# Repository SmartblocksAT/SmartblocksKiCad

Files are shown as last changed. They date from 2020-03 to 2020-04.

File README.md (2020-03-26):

# SmartblocksKiCad
These are the schematics-, assembly-, layout plans and other stuff for KiCad.

Smartblocks is a project by students at the [HTL-Waidhofen](https://htlwy.at/).

Smartblocks logo

# Goal
The Goal is to develop a microcontroller environment for students, which should make it easy for them to start programming with microcontrollers.

We started this Project in February of 2019.
In this time a rough concept that defined the function and dimensions was created and presented to teachers who would later use this project. A proof of concept has been worked on in the summer in order to get an idea of how the project could develop and look like.

As soon as the project was successfully submitted, the existing elements of the prototype, such as the web interface, sample programs and the practical structure, were revised and improved.

# Components
This Project consists of two Components:

 - The webinterface (can be found [here](https://github.com/SmartblocksAT/SmartblocksWeb))
 - ESP32 Library (can be found [here](https://github.com/SmartblocksAT/SmartblocksLibrary))
 - Schematics, etc. (this repository)

## Who is responsible for this?
Lukas Kamleitner <lukas.kamleitner@smartblocks.dev>

Maximilian Mernacher <maximilian.mernacher@smartblocks.dev>

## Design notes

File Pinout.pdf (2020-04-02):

Links J6/J7 | | | Vorne J2/J3
Gerät | Pin | I/O | Gerät | Pin | I/O
Analog IN24 | 33 | I | LCD | 21,22 | BUS
Analog IN24 | 34 | I | Taster | 2 | I
Potentiometer | 35 | I | Taster | 13 | I
Analog IN10 | 36 | I | Taster | 32 | I
Analog IN10 | 39 | I | Led | 4 | O
DAC | 25 | O | Led | 16 | O
DAC | 26 | O | Led | 17 | O
Vorne J2/J3 | | | Rechts J4/J5
Gerät | Pin | I/O | Gerät | Pin | I/O
Realis | 13 | O | Ultraschall(HC-SR04) | 14,27 | I/O
Realis | 4 | O | Temperatur(Si7020-A20) | 21,22 | BUS
Taster | 2 | I | Acelerometer (LIS3DHTR) | 21,22 | BUS
Taster | 32 | I | Lichtsensor(OPT3001) | 21,22 | BUS
DO 24V | 16 | O
DO 24V | 17 | O
Modul 1 | Modul 2
Modul 3 | Modul 4

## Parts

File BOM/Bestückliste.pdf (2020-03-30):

Referenz | Wert | Footprint | Anzahl Sonsitges
C1 C2 C6 C7 C8 C9 C10 C13 C14 C15 C16 C17 C18 C19 C20 C21 C22 C23 C24 C25 C26 C27 C28 C29 C30 | 47pF | C_0805_2012Metric | 25 Capacitor 0805 47pF
C3 C5 | 100pF | C_0805_2012Metric | 2 Capacitor 0805 100pF
C4 C11 C32 C33 | 1uF | C_0805_2012Metric | 4 Capacitor 0805 1uF
D1 | SP0503BAHT | SOT-143 | 1 SP0503BAHT SOT-143
D2 | 1N5819HW-7-F | SOD 123 | 1 1N5819HW-7-F SOD-123
D3 | Led Smd 1206 | LED_1206_3216Metric | 1 Led Smd 1206
J1 | Micro-B_Wuerth_629105150521 | USB_Micro-B_Wuerth_629105150521_CircularHoles | 1 USB B Micro-B_Wuerth_629105150521
J2 J4 J6 | Stecker Messerleiste WSL 10G | SHDR10W64P254X254_2X5_2032X880X915P | 3 Stecker Messerleiste WSL 10G
J3 | Stecker Messerleiste WSL 10G | SHDR10W64P254X254_2X5_2032X880X915P | 1 Stecker Messerleiste WSL 10G
J5 | Stecker Messerleiste WSL 10G | SHDR10W64P254X254_2X5_2032X880X915P | 1 Stecker Messerleiste WSL 10G
J7 | Stecker Messerleiste WSL 10G | SHDR10W64P254X254_2X5_2032X880X915P | 1 Stecker Messerleiste WSL 10G
Q1 Q2 | BC817 | SOT-23 | 2 BC817 SOT-23
R1 R2 | 22R | R_0805_2012Metric | 2 Resistor 0805 22R
R13 | 2k2 | R_0805_2012Metric | 1 Resistor 0805 2k2
R14 | 22,1k | R_0805_2012Metric | 1 Resistor 0805 22,1k
R15 | 47,5k | R_0805_2012Metric | 1 Resistor 0805 47,5k
R3 R4 R8 R33 R34 | 10k | R_0805_2012Metric | 5 Resistor 0805 10k
R35 | 1M | R_0805_2012Metric | 1 Resistor 0805 1M
R36 | 330R | R_0805_2012Metric | 1 Resistor 0805 330R
R5 R6 R7 R10 R12 R16 R17 R18 R19 R20 R21 R22 R23 R24 R25 R26 R27 R28 R29 R30 R31 R32 | 47R | R_0805_2012Metric | 22 Resistor 0805 47R
R9 R11 | 4k7 | R_0805_2012Metric | 2 Resistor 0805 4k7
S1 | B3SL-1002P | SW_SPST_B3SL-1002P | 1 Button SMD B3SL-1002P
S2 | B3SL-1002P | SW_SPST_B3SL-1002P | 1 Button SMD B3SL-1002P
U1 | CP2102N-A01-GQFN24 | QFN-24-1EP_4x4mm_P0.5mm_EP2.6x2.6mm | 1 CP2102N-A01-G QFN24
U2 | EP32-WROOM-32D | ESP32-WROOM-32U | 1 EP32-WROOM-32D
U3 | AMS1117-3.3 | SOT-223-3_TabPin2 | 1 AMS1117-3.3 SOT-223-3

## Mainboard

Referenz | Wert | Footprint | Anzahl Sonstiges
C1 C2 C3 C4 C5 C6 C7 C8 C9 10nF | C_0805_2012Metric | 9 Capacitor 0805 10nF
J3 | Stecker Messerleiste WSL 10G | SHDR10W64P254X254_2X5_2032X880X915P | 1 Stecker Messerleiste WSL 10G
J1 | Stecker Messerleiste WSL 10G | SHDR10W64P254X254_2X5_2032X880X915P | 1 Stecker Messerleiste WSL 10G
J2 J4 J5 J6 | TBL 127B p2 | TBL_127B 2 | 4 TBL 127B p2
R5 | 100R | R_0805_2012Metric | 1 Resistor 0805 100R
R_POT1 | 10K_Pot | Potentiometer_Bourns_PRS11S_Vertical | 1 10K_Pot Bourns_PRS11S_Vertical
R1 R3 R6 R8 | 10k | R_0805_2012Metric | 4 Resistor 0805 10k
R2 R9 | 1k6 | R_0805_2012Metric | 2 Resistor 0805 1k6
R4 R7 | 4k7 | R_0805_2012Metric | 2 Resistor 0805 4k7
U1 U2 | AD8603 | TSOT-23-5 | 2 AD8603 TSOT-23-5

# Modul1

Referenz | Wert | Footprint | Anazhl Sonstiges
C1 C2 C3 C4 C5 10nF | C_0805_2012Metric | 5 Capacitor 0805 10nF
D1 D2 D3 | Led THT d5mm | D_DO-15_P5.08mm_Vertical_KathodeUp | 3 Led d5mm
J1 | Stecker Messerleiste WSL 10G | SHDR10W64P254X254_2X5_2032X880X915P | 1 Stecker Messerleiste WSL 10G
J2 | Stecker Messerleiste WSL 10G | SHDR10W64P254X254_2X5_2032X880X915P | 1 Stecker Messerleiste WSL 10G
J3 | LCD Dobrovitz | LCD_dobrovitz | 1 LCD Dobrovitz
Q1 | BC817 | SOT-23 | 1 BC817 SOT-23
R1 R2 R6 R8 | 10k | R_0805_2012Metric | 4 Resistor 0805 10k
R3 R5 R7 | 220R | R_0805_2012Metric | 3 Resistor 0805 220R
RV1 | R_POT 10k | Potentiometer_Bourns_3314G_Vertical | 1 R_POT 10k Bourns_3314G_Vertical
SW1 SW3 SW4 B077FH7TGD Taster | Druckschalter | 3 B077FH7TGD Taster
U1 | PCF8574 | SOIC-16W_7.5x10.3mm_P1.27mm | 1 PCF8574AT SOIC-16W

# Modul 2

Referenz | Wert | Footprint | Anzahl Sonstiges
C3 C4 C9 C10 | 100nF | C_0805_2012Metric | 4 Capacitor 0805 100nF
C1 C2 | 10nF | C_0805_2012Metric | 2 Capacitor 0805 10nF
C13 C14 | 10uF | CP_Radial_D5.0mm_P2.00mm | 2 Capacitor 0805 10uF
C5 C6 C7 C8 C11 C12 1uF | C_0805_2012Metric | 6 Capacitor 0805 1uF
D1 D2 D3 D4 | 1N4148 | D_SOD-123 | 4 1N4148
J2 | Stecker Messerleiste WSL 10G SHDR10W64P254X254_2X5_2032X880X915P | 1 Stecker Messerleiste WSL 10G
J3 | Stecker Messerleiste WSL 10G SHDR10W64P254X254_2X5_2032X880X915P | 1 Stecker Messerleiste WSL 10G
J1 J5 | TBL 127B p2 | TBL_127B 2 | 2 TBL 127B p2
J4 J6 | TBL 127B p3 | TBL_127B 3 | 2 TBL 127B p3
K1 K2 | Songle Relay TypC | Relay_SPDT_SANYOU_SRD_Series_Form_C | 2 Songle Relay TypC
Q9 Q10 | BC817 | SOT-23 | 2 BC817 SOT-23
Q1 Q2 Q3 Q4 | NVD5C454NT4G | TO-252-2 | 4 NVD5C454NT4G TO-252-2
R1 R2 | 100K | R_0805_2012Metric | 2 Resistor 0805 100k
R3 R4 | 100R | R_0805_2012Metric | 2 Resistor 0805 100R
R10 R11 R12 R14 | 10K | R_0805_2012Metric | 4 Resistor 0805 10k
R9 R13 | 5K6 | R_0805_2012Metric | 2 Resistor 0805 5k6
SW1 SW2 | SW_DIP_x01 | Druckschalter | 2 B077FH7TGD Taster
U1 U2 | si8234bb | SOIC-16W_7.5x10.3mm_P1.27mm | 2 si8234bb SOIC-16W

# Modul3

Referenz | Wert | Footprint | Anzahl | Sonsitges
AC1 | LIS3DHTR | XDCR_LIS3DHTR | | 1 LIS3DHTR LGA-16
C1 C4 C5 C6 | 1pF | C_0805_2012Metric | | 4 Capacitor 0805 1pF
C2 C3 | 47pF | C_0805_2012Metric | | 2 Capacitor 0805 1pF
IC1 | OPT3001DNPR | OPT3001DNPR | | 1 OPT3001DNPR USON-6
J5 | Stecker Messerleiste WSL 10G | SHDR10W64P254X254_2X5_2032X880X915P | | 1 Stecker Messerleiste WSL 10G
J4 | Stecker Messerleiste WSL 10G | SHDR10W64P254X254_2X5_2032X880X915P | | 1 Stecker Messerleiste WSL 10G
J1 | HC-SR04 | XCVR_HC-SR04 | | 1 HC-SR04
R3 R4 | 10K | R_0805_2012Metric | | 2 Resistor 0805 10k
R1 R2 | 47R | R_0805_2012Metric | | 2 Resistor 0805 47R
U1 | Si7020-A20 DFN-6 | DFN-6-1EP_3x3mm_P1mm_EP1.5x2.4mm | | 1 Si7020-A20 DFN_QFN

# Modul4

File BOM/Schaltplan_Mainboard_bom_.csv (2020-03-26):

Component | Description | Part | References | Value | Footprint | Quantity Per PCB | Datasheet
1 | Unpolarized capacitor | C | C3 C5 | 100pF | C_0805_2012Metric | 2 | Capacitor 0805 100pF
2 | Unpolarized capacitor | C | C4 C11 C32 C33 | 1uF | C_0805_2012Metric | 4 | Capacitor 0805 1uF
3 | Unpolarized capacitor | C | C1 C2 C6 C7 C8 C9 C10 C13 C14 C15 C16 C17 C18 C19 C20 C21 C22 C23 C24 C25 C26 C27 C28 C29 C30 | 47pF | C_0805_2012Metric | 25 | Capacitor 0805 47pF
4 | 30V 1A Schottky Barrier Rectifier Diode, DO-41 | 1N5818 | D2 | 1N5819HW-7-F | D_ | 1 | 1N5819HW-7-F SOD-123
5 | LED generic | LED | D3 | Led Spannung | LED_1206_3216Metric | 1 | Led Smd 1206
6 |  | SP0503BAHT-Power_Protection | D1 | SP0503BAHT | SOT-143 | 1 | SP0503BAHT SOT-143
7 | Generic connector, double row, 02x01, this symbol is compatible with counter-clockwise, top-bottom and odd-even numbering schemes., script generated (kicad-library-utils/schlib/autogen/connector/) | Conn_02x01 | J5 | Conn_Rechts | SHDR10W64P254X254_2X5_2032X880X915P | 1 | Stecker Messerleiste WSL 10G
8 | Generic connector, double row, 02x05, odd/even pin numbering scheme (row 1 odd numbers, row 2 even numbers), script generated (kicad-library-utils/schlib/autogen/connector/) | Conn_02x05_Odd_Even | J2 J4 J6 | ConnectorBUS_Front | SHDR10W64P254X254_2X5_2032X880X915P | 3 | Stecker Messerleiste WSL 10G
9 | Generic connector, double row, 02x03, odd/even pin numbering scheme (row 1 odd numbers, row 2 even numbers), script generated (kicad-library-utils/schlib/autogen/connector/) | Conn_02x03_Odd_Even | J3 | Connector_Front | SHDR10W64P254X254_2X5_2032X880X915P | 1 | Stecker Messerleiste WSL 10G
10 | Generic connector, double row, 02x04, odd/even pin numbering scheme (row 1 odd numbers, row 2 even numbers), script generated (kicad-library-utils/schlib/autogen/connector/) | Conn_02x04_Odd_Even | J7 | Connector_Links | SHDR10W64P254X254_2X5_2032X880X915P | 1 | Stecker Messerleiste WSL 10G
11 | USB Micro Type B connector | USB_B_Micro | J1 | Micro-B_Wuerth_629105150521 | USB_Micro-B_Wuerth_629105150521_CircularHoles | 1 | USB B Micro-B_Wuerth_629105150521
12 | 0.8A Ic, 45V Vce, NPN Transistor, SOT-23 | BC817 | Q1 Q2 | BC817 | SOT-23 | 2 | BC817 SOT-23
13 | Resistor | R | R3 R4 R8 R33 R34 | 10k | R_0805_2012Metric | 5 | Resistor 0805 10k
14 | Resistor | R | R35 | 1M NC | R_0805_2012Metric | 1 | Resistor 0805 1M
15 | Resistor | R | R14 | 22,1k | R_0805_2012Metric | 1 | Resistor 0805 22,1k
16 | Resistor | R | R1 R2 | 22R | R_0805_2012Metric | 2 | Resistor 0805 22R
17 | Resistor | R | R13 | 2k2 | R_0805_2012Metric | 1 | Resistor 0805 2k2
18 | Resistor | R | R36 | 330R | R_0805_2012Metric | 1 | Resistor 0805 330R
19 | Resistor | R | R15 | 47,5k | R_0805_2012Metric | 1 | Resistor 0805 47,5k
20 | Resistor | R | R5 R6 R7 R10 R12 R16 R17 R18 R19 R20 R21 R22 R23 R24 R25 R26 R27 R28 R29 R30 R31 R32 | 47R | R_0805_2012Metric | 22 | Resistor 0805 47R
21 | Resistor | R | R9 R11 | 4k7 | R_0805_2012Metric | 2 | Resistor 0805 4k7
22 | 1x DIP Switch, Single Pole Single Throw (SPST) switch, small symbol | SW_DIP_x01 | S1 | BOOT Option | SW_SPST_B3SL-1002P | 1 | Button SMD B3SL-1002P
23 | 1x DIP Switch, Single Pole Single Throw (SPST) switch, small symbol | SW_DIP_x01 | S2 | Reset | SW_SPST_B3SL-1002P | 1 | Button SMD B3SL-1002P
24 | 1A Low Dropout regulator, positive, 3.3V fixed output, SOT-223 | AMS1117-3.3 | U3 | AMS1117-3.3 | SOT-223-3_TabPin2 | 1 | AMS1117-3.3 SOT-223-3
25 | USB to UART master bridge | CP2102N-A01-GQFN24 | U1 | CP2102N-A01-GQFN24 | QFN-24-1EP_4x4mm_P0.5mm_EP2.6x2.6mm | 1 | CP2102N-A01-G QFN24
26 |  | EP32-WROOM-32D | U2 | EP32-WROOM-32D | ESP32-WROOM-32U | 1 | EP32-WROOM-32D
Component Groups: | 26
Component Count: | 84
Fitted Components: | 84
Number of PCBs: | 1
Total components: | 84
Schematic Version:
Schematic Date:
PCB Variant: | [u'default']
BoM Date: | 15.03.2020 14:47:03
Schematic Source: | Schaltplan_Mainboard.sch
KiCad Version: | Eeschema (5.0.0)

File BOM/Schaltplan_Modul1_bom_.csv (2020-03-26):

Component | Description | Part | References | Value | Footprint | Quantity Per PCB | Datasheet
1 | Unpolarized capacitor | C | C1 C2 C3 C4 C5 C6 C7 C8 C9 | 10nF | C_0805_2012Metric | 9 | Capacitor 0805 10nF
2 | Generic connector, double row, 02x05, odd/even pin numbering scheme (row 1 odd numbers, row 2 even numbers), script generated (kicad-library-utils/schlib/autogen/connector/) | Conn_02x05_Odd_Even | J3 | ConnectorBUS_Links | SHDR10W64P254X254_2X5_2032X880X915P | 1 | Stecker Messerleiste WSL 10G
3 | Generic connector, double row, 02x04, odd/even pin numbering scheme (row 1 odd numbers, row 2 even numbers), script generated (kicad-library-utils/schlib/autogen/connector/) | Conn_02x04_Odd_Even | J1 | Connector_Links | SHDR10W64P254X254_2X5_2032X880X915P | 1 | Stecker Messerleiste WSL 10G
4 | Generic screw terminal, single row, 01x02, script generated (kicad-library-utils/schlib/autogen/connector/) | Screw_Terminal_01x02 | J2 J4 J5 J6 | X_DAC | TBL_127B 2 | 4 | TBL 127B p2
5 | Resistor | R | R5 | 100R | R_0805_2012Metric | 1 | Resistor 0805 100R
6 | Potentiometer | R_POT | R_POT1 | 10K_Pot | Potentiometer_Bourns_PRS11S_Vertical | 1 | 10K_Pot Bourns_PRS11S_Vertical
7 | Resistor | R | R1 R3 R6 R8 | 10k | R_0805_2012Metric | 4 | Resistor 0805 10k
8 | Resistor | R | R2 R9 | 1k6 | R_0805_2012Metric | 2 | Resistor 0805 1k6
9 | Resistor | R | R4 R7 | 4k7 | R_0805_2012Metric | 2 | Resistor 0805 4k7
10 | Precision Micropower, Low Noise CMOS, Rail-to-Rail Input/Output Operational Amplifier, TSOT-23-5 | AD8603 | U1 U2 | AD8603 | TSOT-23-5 | 2 | AD8603 TSOT-23-5
Component Groups: | 10
Component Count: | 27
Fitted Components: | 27
Number of PCBs: | 1
Total components: | 27
Schematic Version:
Schematic Date:
PCB Variant: | [u'default']
BoM Date: | 15.03.2020 14:37:26
Schematic Source: | Schaltplan_Modul1.sch
KiCad Version: | Eeschema (5.0.0)

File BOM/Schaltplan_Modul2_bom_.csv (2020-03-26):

Component | Description | Part | References | Value | Footprint | Quantity Per PCB | Datasheet
1 | Unpolarized capacitor | C | C1 C2 C3 C4 C5 | 10nF | C_0805_2012Metric | 5 | Capacitor 0805 10nF
2 | LED generic | LED | D1 D2 D3 | Led THT | D_DO-15_P5.08mm_Vertical_KathodeUp | 3 | Led Smd 1206 d5mm
3 | Generic connector, double row, 02x05, odd/even pin numbering scheme (row 1 odd numbers, row 2 even numbers), script generated (kicad-library-utils/schlib/autogen/connector/) | Conn_02x05_Odd_Even | J1 | ConnectorBUS_Front | SHDR10W64P254X254_2X5_2032X880X915P | 1 | Stecker Messerleiste WSL 10G
4 | Generic connector, double row, 02x03, odd/even pin numbering scheme (row 1 odd numbers, row 2 even numbers), script generated (kicad-library-utils/schlib/autogen/connector/) | Conn_02x03_Odd_Even | J2 | Connector_Front | SHDR10W64P254X254_2X5_2032X880X915P | 1 | Stecker Messerleiste WSL 10G
5 | Generic connector, single row, 01x16, script generated (kicad-library-utils/schlib/autogen/connector/) | Conn_01x16_Male | J3 | LCD Dobrovitz | LCD_dobro | 1 | LCD Dobrovitz
6 | 0.8A Ic, 45V Vce, NPN Transistor, SOT-23 | BC817 | Q1 | BC817 | SOT-23 | 1 | BC817 SOT-23
7 | Resistor | R | R1 R2 R6 R8 | 10k | R_0805_2012Metric | 4 | Resistor 0805 10k
8 | Resistor | R | R3 R5 R7 | 220R | R_0805_2012Metric | 3 | Resistor 0805 220R
9 | Potentiometer | R_POT | RV1 | R_POT 10k | Potentiometer_Bourns_3314G_Vertical | 1 | R_POT 10k Bourns_3314G_Vertical
10 | 1x DIP Switch, Single Pole Single Throw (SPST) switch, small symbol | SW_DIP_x01 | SW1 SW3 SW4 | SW_DIP_x01 | Druckschalter | 3 | B077FH7TGD Taster
11 | 8 Bit Port/Expander to I2C Bus, DIP/SOIC-16 | PCF8574A | U1 | PCF8574 | SOIC-16W_7.5x10.3mm_P1.27mm | 1 | PCF8574AT SOIC-16W
Component Groups: | 11
Component Count: | 24
Fitted Components: | 24
Number of PCBs: | 1
Total components: | 24
Schematic Version:
Schematic Date:
PCB Variant: | [u'default']
BoM Date: | 15.03.2020 14:37:44
Schematic Source: | Schaltplan_Modul2.sch
KiCad Version: | Eeschema (5.0.0)

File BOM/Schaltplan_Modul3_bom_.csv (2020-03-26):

Component | Description | Part | References | Value | Footprint | Quantity Per PCB | Datasheet
1 | Unpolarized capacitor | C | C3 C4 C9 C10 | 100nF | C_0805_2012Metric | 4 | Capacitor 0805 100nF
2 | Unpolarized capacitor | C | C1 C2 | 10nF | C_0805_2012Metric | 2 | Capacitor 0805 10nF
3 | Polarised capacitor | CP | C13 C14 | 10uF | CP_Radial_D5.0mm_P2.00mm | 2 | Capacitor 0805 10uF
4 | Unpolarized capacitor | C | C5 C6 C7 C8 C11 C12 | 1uF | C_0805_2012Metric | 6 | Capacitor 0805 1uF
5 | 100V 0.15A standard switching diode, DO-35 | 1N4148 | D1 D2 D3 D4 | 1N4148 | D_SOD-123 | 4 | 1N4148
6 | Generic connector, double row, 02x05, odd/even pin numbering scheme (row 1 odd numbers, row 2 even numbers), script generated (kicad-library-utils/schlib/autogen/connector/) | Conn_02x05_Odd_Even | J2 | ConnectorBUS_Rechts | SHDR10W64P254X254_2X5_2032X880X915P | 1 | Stecker Messerleiste WSL 10G
7 | Generic connector, double row, 02x03, odd/even pin numbering scheme (row 1 odd numbers, row 2 even numbers), script generated (kicad-library-utils/schlib/autogen/connector/) | Conn_02x03_Odd_Even | J3 | Connector_Rechts | SHDR10W64P254X254_2X5_2032X880X915P | 1 | Stecker Messerleiste WSL 10G
8 | Generic screw terminal, single row, 01x02, script generated (kicad-library-utils/schlib/autogen/connector/) | Screw_Terminal_01x02 | J1 J5 | Mosfets | TBL_127B 2 | 2 | TBL 127B p2
9 | Generic screw terminal, single row, 01x03, script generated (kicad-library-utils/schlib/autogen/connector/) | Screw_Terminal_01x03 | J4 J6 | Relais | TBL_127B 3 | 2 | TBL 127B p3
10 | Sanyo SRD relay, Single Pole Miniature Power Relay, | SANYOU_SRD_Form_C | K1 K2 | SANYOU_SRD_Form_C | Relay_SPDT_SANYOU_SRD_Series_Form_C | 2 | SANYOU_SRD_Form_C
11 | 0.8A Ic, 45V Vce, NPN Transistor, SOT-23 | BC817 | Q9 Q10 | BC817 | SOT-23 | 2 | BC817 SOT-23
12 | Transistor N-MOSFET with substrate diode (general) | Q_NMOS_GDS | Q1 Q2 Q3 Q4 | NVD5C454NT4G | TO-252-2 | 4 | NVD5C454NT4G TO-252-2
13 | Resistor | R | R1 R2 | 100K | R_0805_2012Metric | 2 | Resistor 0805 100k
14 | Resistor | R | R3 R4 | 100R | R_0805_2012Metric | 2 | Resistor 0805 100R
15 | Resistor | R | R10 R11 R12 R14 | 10K | R_0805_2012Metric | 4 | Resistor 0805 10k
16 | Resistor | R | R9 R13 | 5K6 | R_0805_2012Metric | 2 | Resistor 0805 5k6
17 | 1x DIP Switch, Single Pole Single Throw (SPST) switch, small symbol | SW_DIP_x01 | SW1 SW2 | SW_DIP_x01 | Druckschalter | 2 | B077FH7TGD Taster
18 |  | si8234bb | U1 U2 | si8234bb | SOIC-16W_7.5x10.3mm_P1.27mm | 2 | si8234bb SOIC-16W
Component Groups: | 18
Component Count: | 46
Fitted Components: | 46
Number of PCBs: | 1
Total components: | 46
Schematic Version:
Schematic Date:
PCB Variant: | [u'default']
BoM Date: | 15.03.2020 15:04:35
Schematic Source: | Schaltplan_Modul3.sch
KiCad Version: | Eeschema (5.0.0)

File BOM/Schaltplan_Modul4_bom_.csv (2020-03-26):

Component | Description | Part | References | Value | Footprint | Quantity Per PCB | Datasheet
1 | Accelerometer 3-Axis 2g/16g 1.8V LGA16 STMicroelectronics LIS3DHTR Accelerometer IC, 3-axis, I2C, SPI 1.71 3.6 V, 16-Pin LGA | LIS3DHTR | AC1 | LIS3DHTR | XDCR_LIS3DHTR | 1 | LIS3DHTR LGA-16
2 | Unpolarized capacitor | C | C1 C4 C5 C6 | 1pF | C_0805_2012Metric | 4 | Capacitor 0805 1pF
3 | Unpolarized capacitor | C | C2 C3 | 47pF | C_0805_2012Metric | 2 | Capacitor 0805 1pF
4 | Digital Ambient Light Sensor (ALS) With High-Precision Human-Eye Response | OPT3001DNPR | IC1 | OPT3001DNPR | OPT3001DNPR | 1 | OPT3001DNPR USON-6
5 | Generic connector, double row, 02x01, this symbol is compatible with counter-clockwise, top-bottom and odd-even numbering schemes., script generated (kicad-library-utils/schlib/autogen/connector/) | Conn_02x01 | J5 | Conn_02x01 | SHDR10W64P254X254_2X5_2032X880X915P | 1 | Stecker Messerleiste WSL 10G
6 | Generic connector, double row, 02x05, odd/even pin numbering scheme (row 1 odd numbers, row 2 even numbers), script generated (kicad-library-utils/schlib/autogen/connector/) | Conn_02x05_Odd_Even | J4 | ConnectorBUS_Rechts | SHDR10W64P254X254_2X5_2032X880X915P | 1 | Stecker Messerleiste WSL 10G
7 |  | HC-SR04 | J1 | HC-SR04 | XCVR_HC-SR04 | 1 | HC-SR04
8 | Resistor | R | R3 R4 | 10K | R_0805_2012Metric | 2 | Resistor 0805 10k
9 | Resistor | R | R1 R2 | 47R | R_0805_2012Metric | 2 | Resistor 0805 47R
10 | I2C Humidity and Temperature Sensor, DFN-6 | Si7020-A20 | U1 | Si7020-A20 DFN-6 | DFN-6-1EP_3x3mm_P1mm_EP1.5x2.4mm | 1 | Si7020-A20 DFN_QFN
Component Groups: | 10
Component Count: | 16
Fitted Components: | 16
Number of PCBs: | 1
Total components: | 16
Schematic Version:
Schematic Date:
PCB Variant: | [u'default']
BoM Date: | 15.03.2020 14:37:53
Schematic Source: | Schaltplan_Modul4.sch
KiCad Version: | Eeschema (5.0.0)

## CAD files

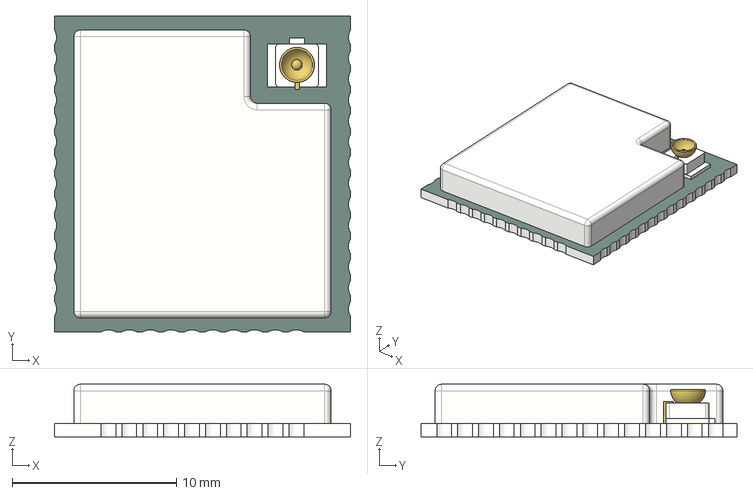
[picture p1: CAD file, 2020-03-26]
Kicad/ESP32-WROOM-32U .stp
18.0 x 19.2 x 3.20 mm

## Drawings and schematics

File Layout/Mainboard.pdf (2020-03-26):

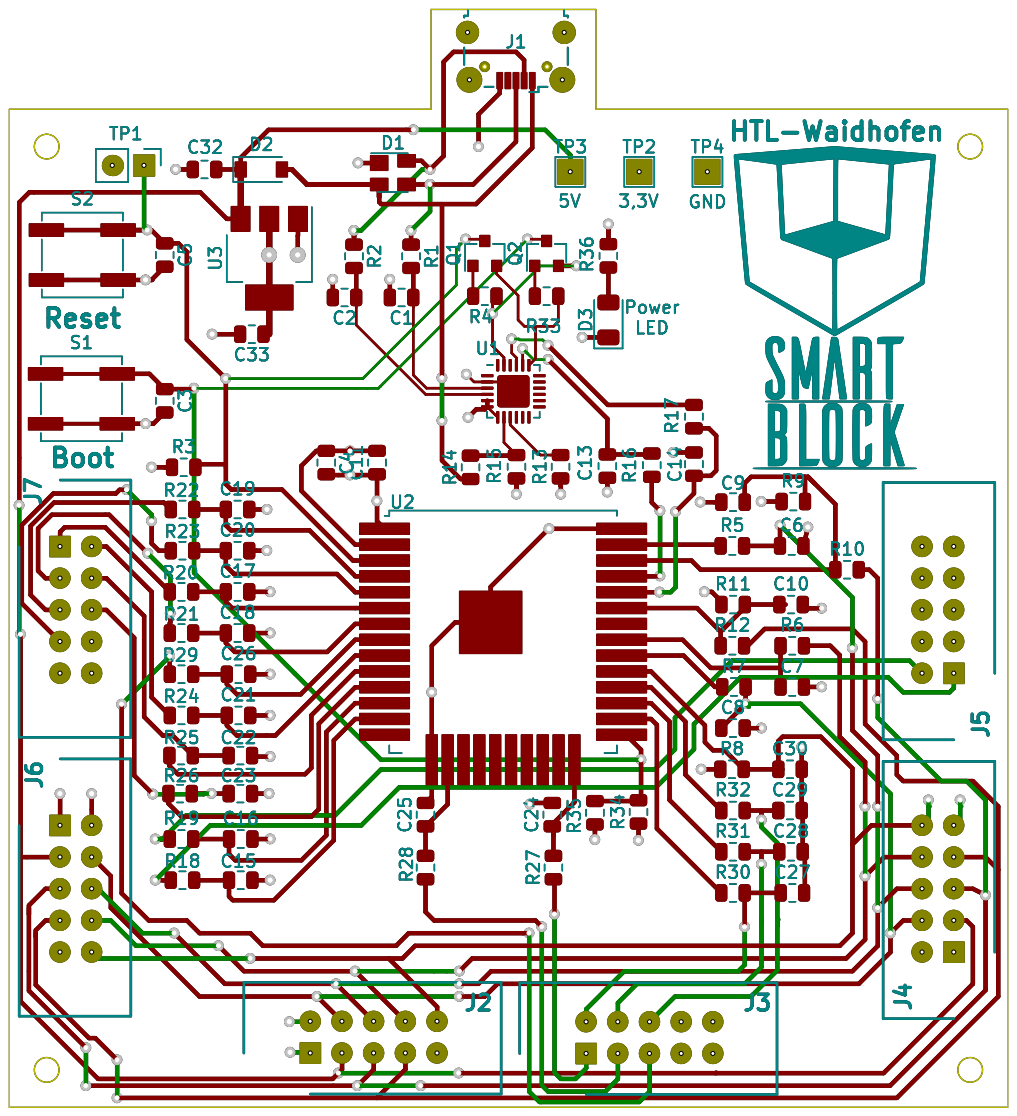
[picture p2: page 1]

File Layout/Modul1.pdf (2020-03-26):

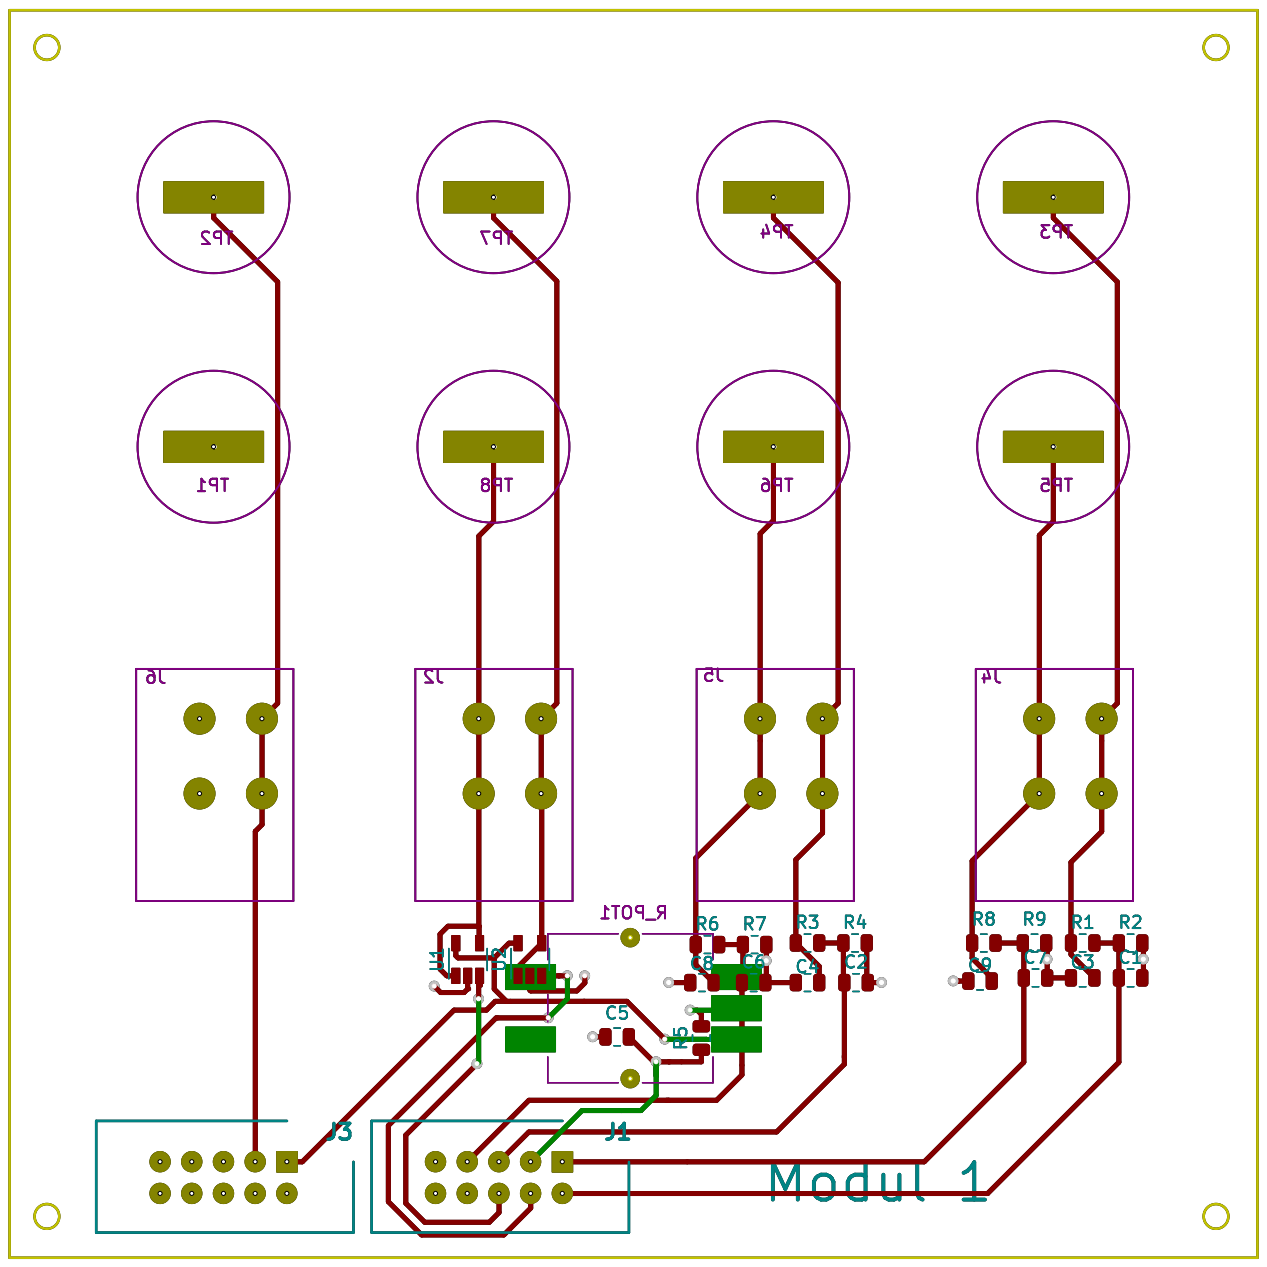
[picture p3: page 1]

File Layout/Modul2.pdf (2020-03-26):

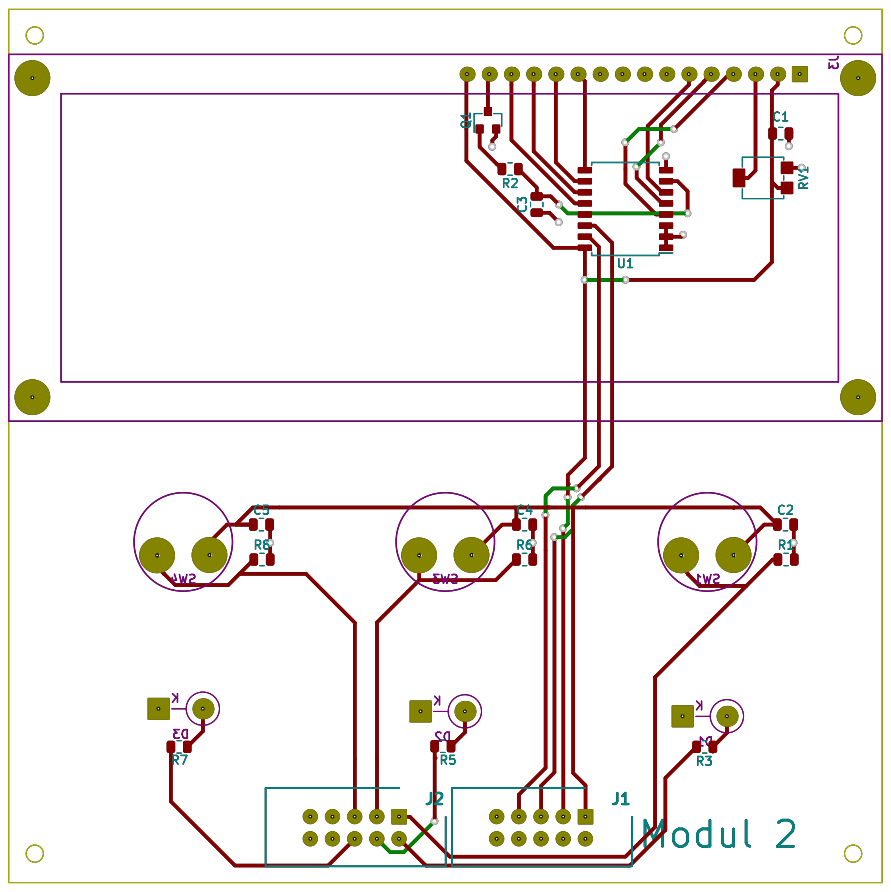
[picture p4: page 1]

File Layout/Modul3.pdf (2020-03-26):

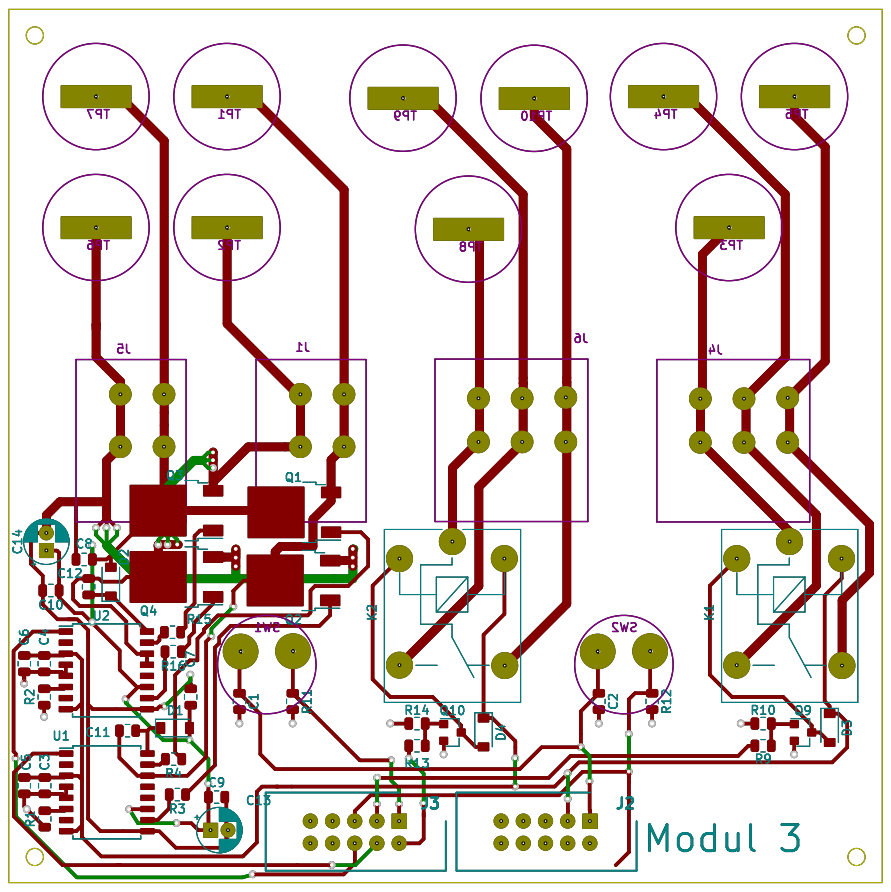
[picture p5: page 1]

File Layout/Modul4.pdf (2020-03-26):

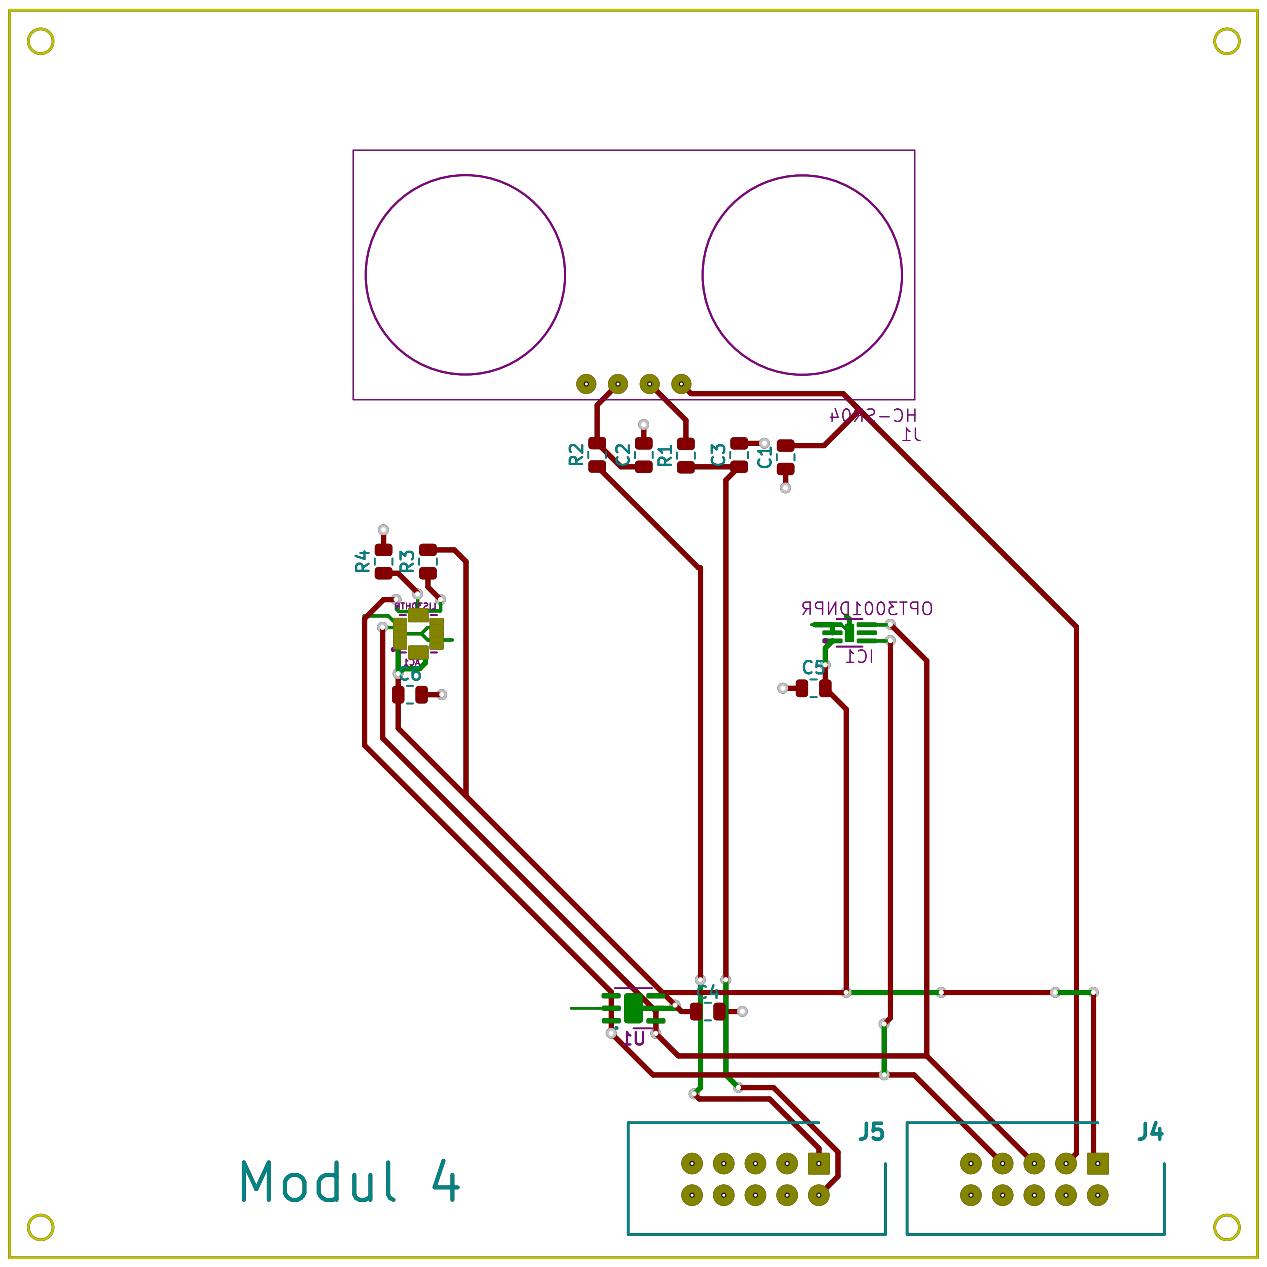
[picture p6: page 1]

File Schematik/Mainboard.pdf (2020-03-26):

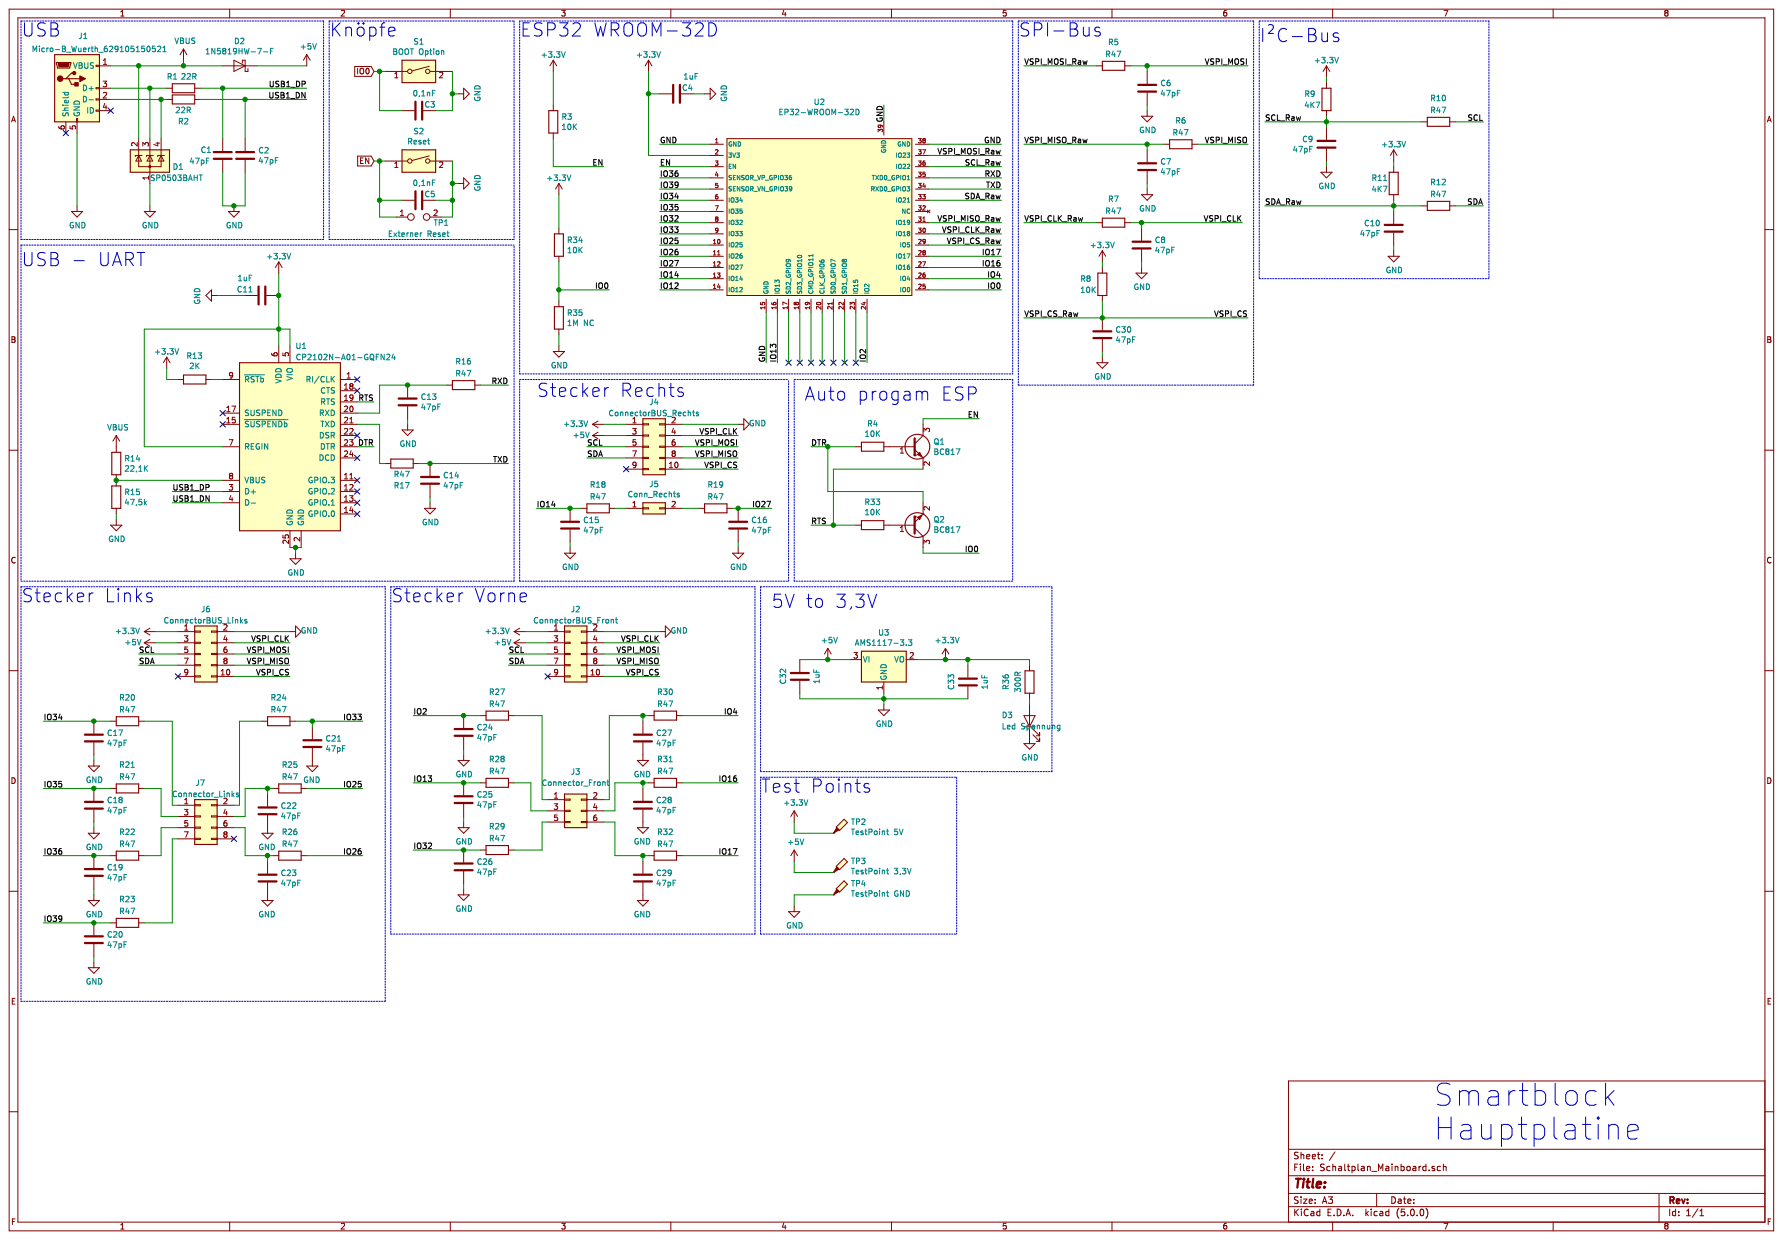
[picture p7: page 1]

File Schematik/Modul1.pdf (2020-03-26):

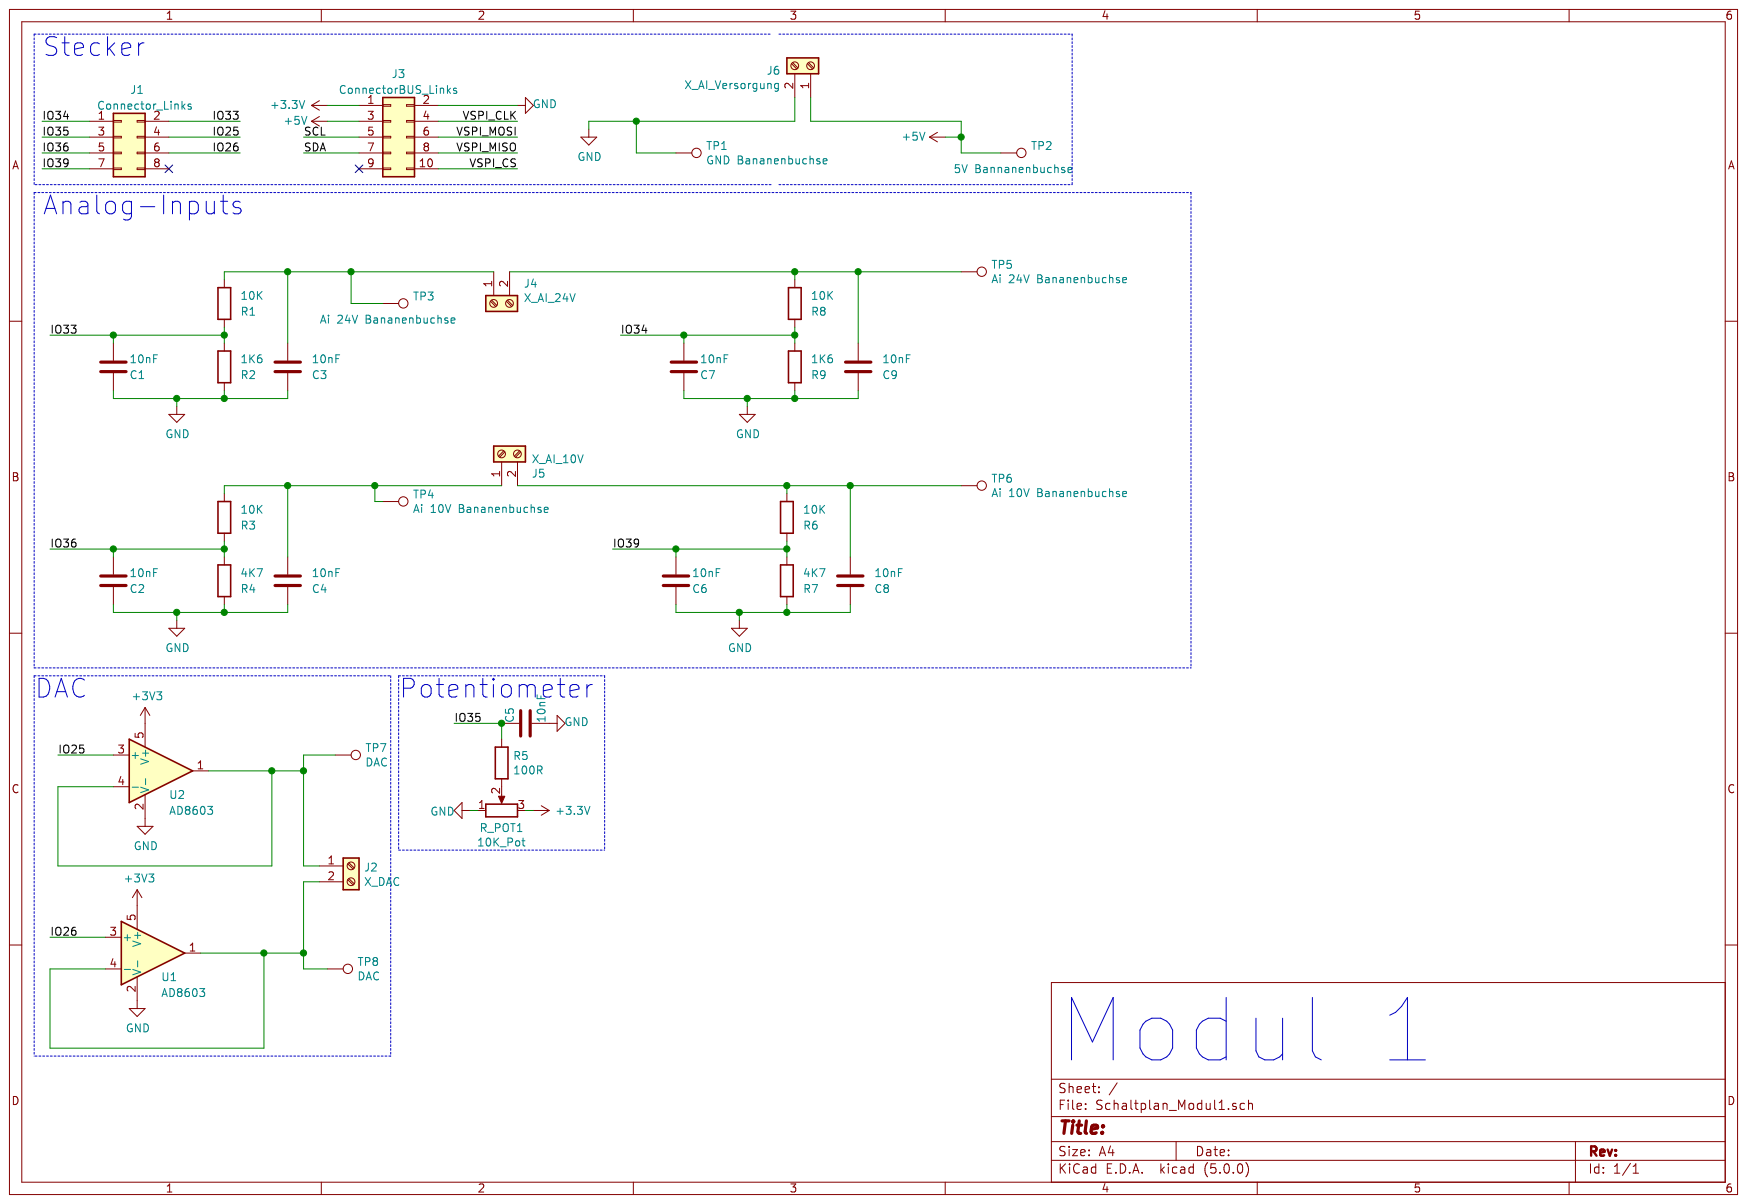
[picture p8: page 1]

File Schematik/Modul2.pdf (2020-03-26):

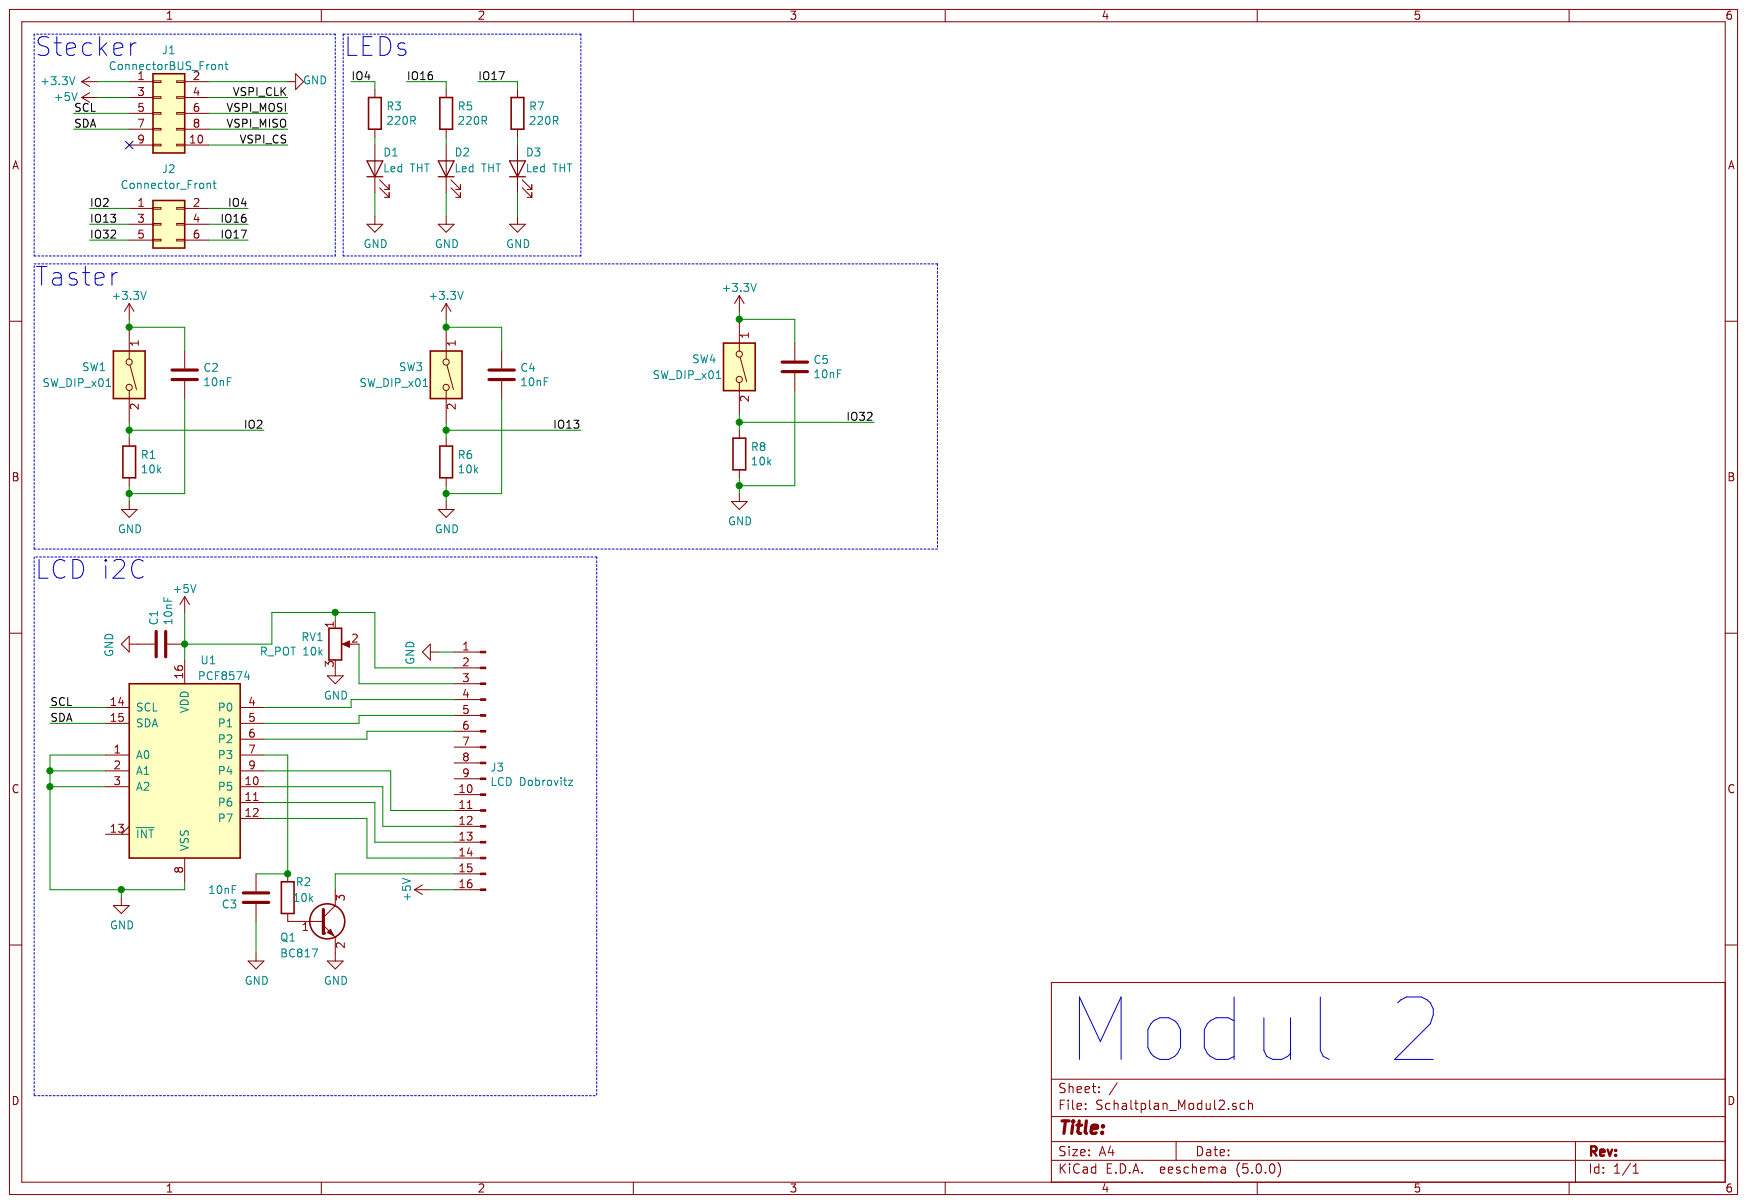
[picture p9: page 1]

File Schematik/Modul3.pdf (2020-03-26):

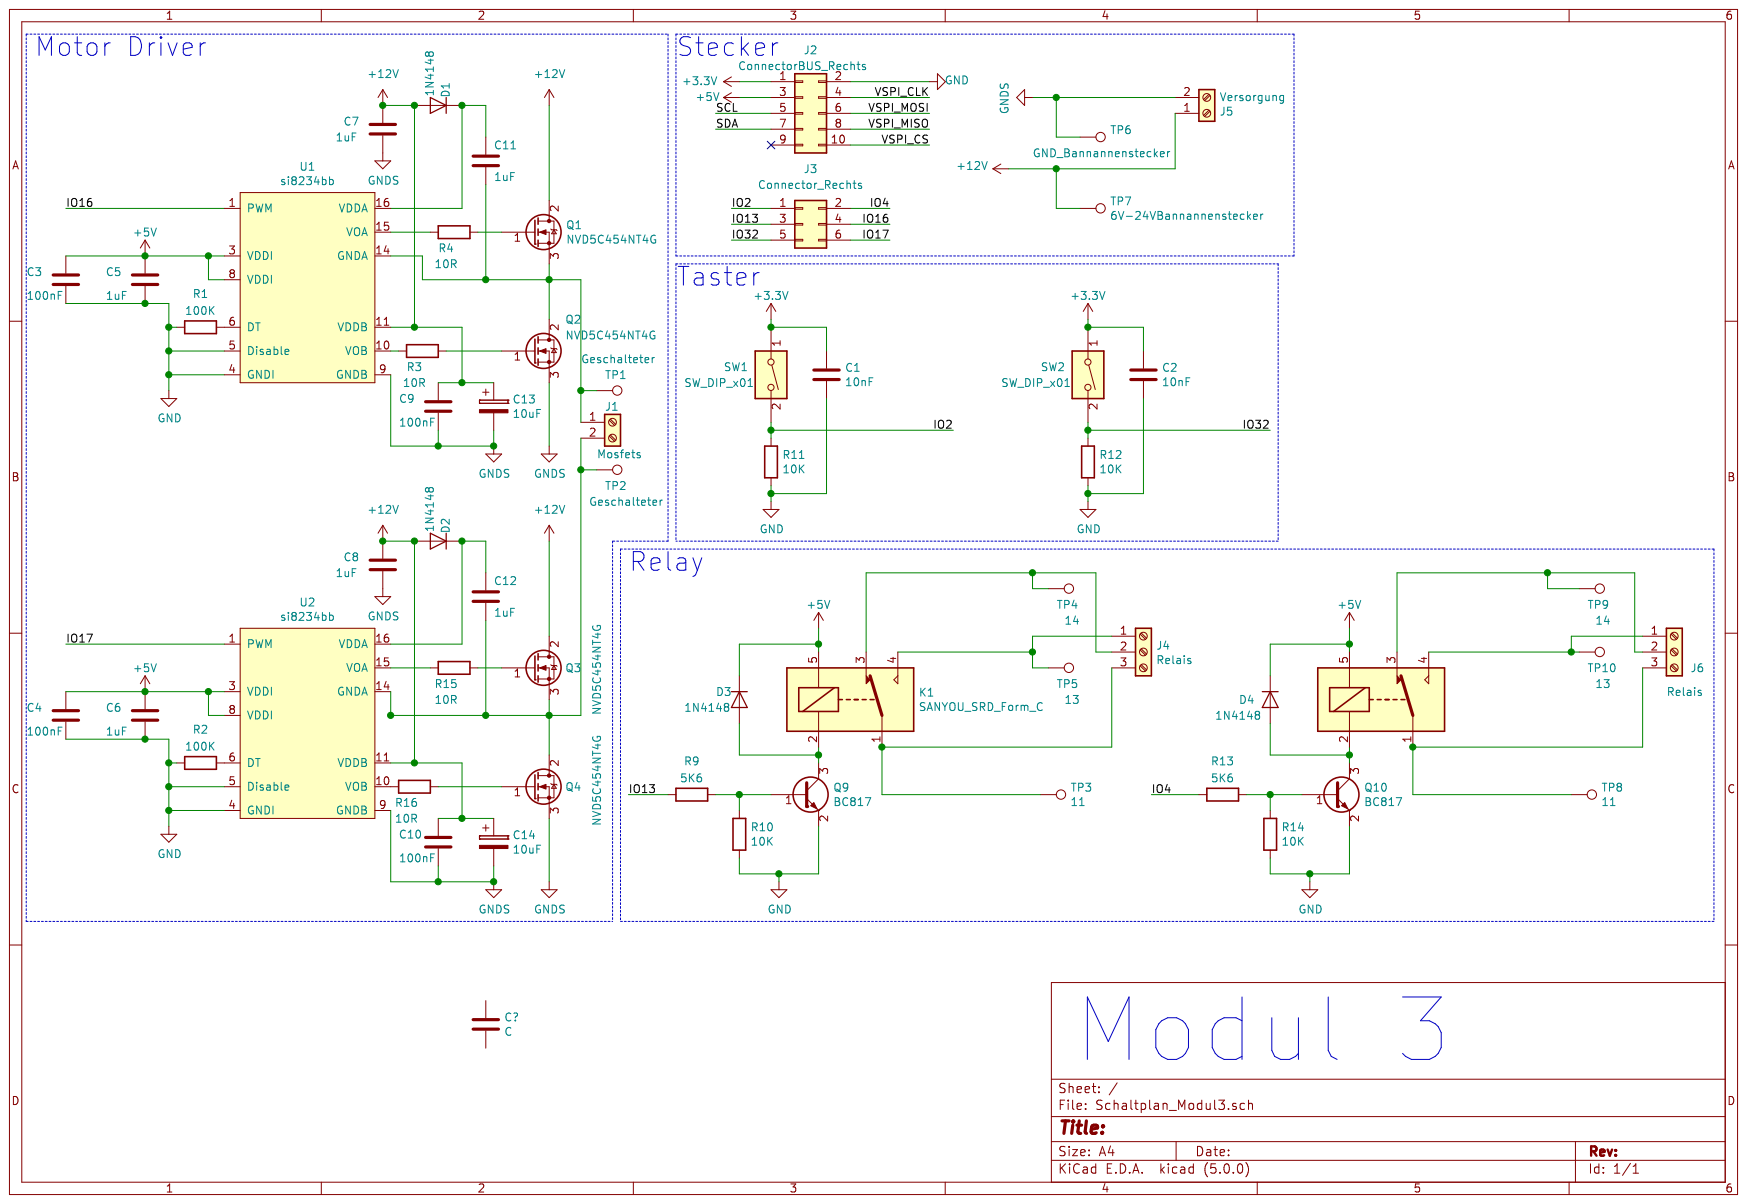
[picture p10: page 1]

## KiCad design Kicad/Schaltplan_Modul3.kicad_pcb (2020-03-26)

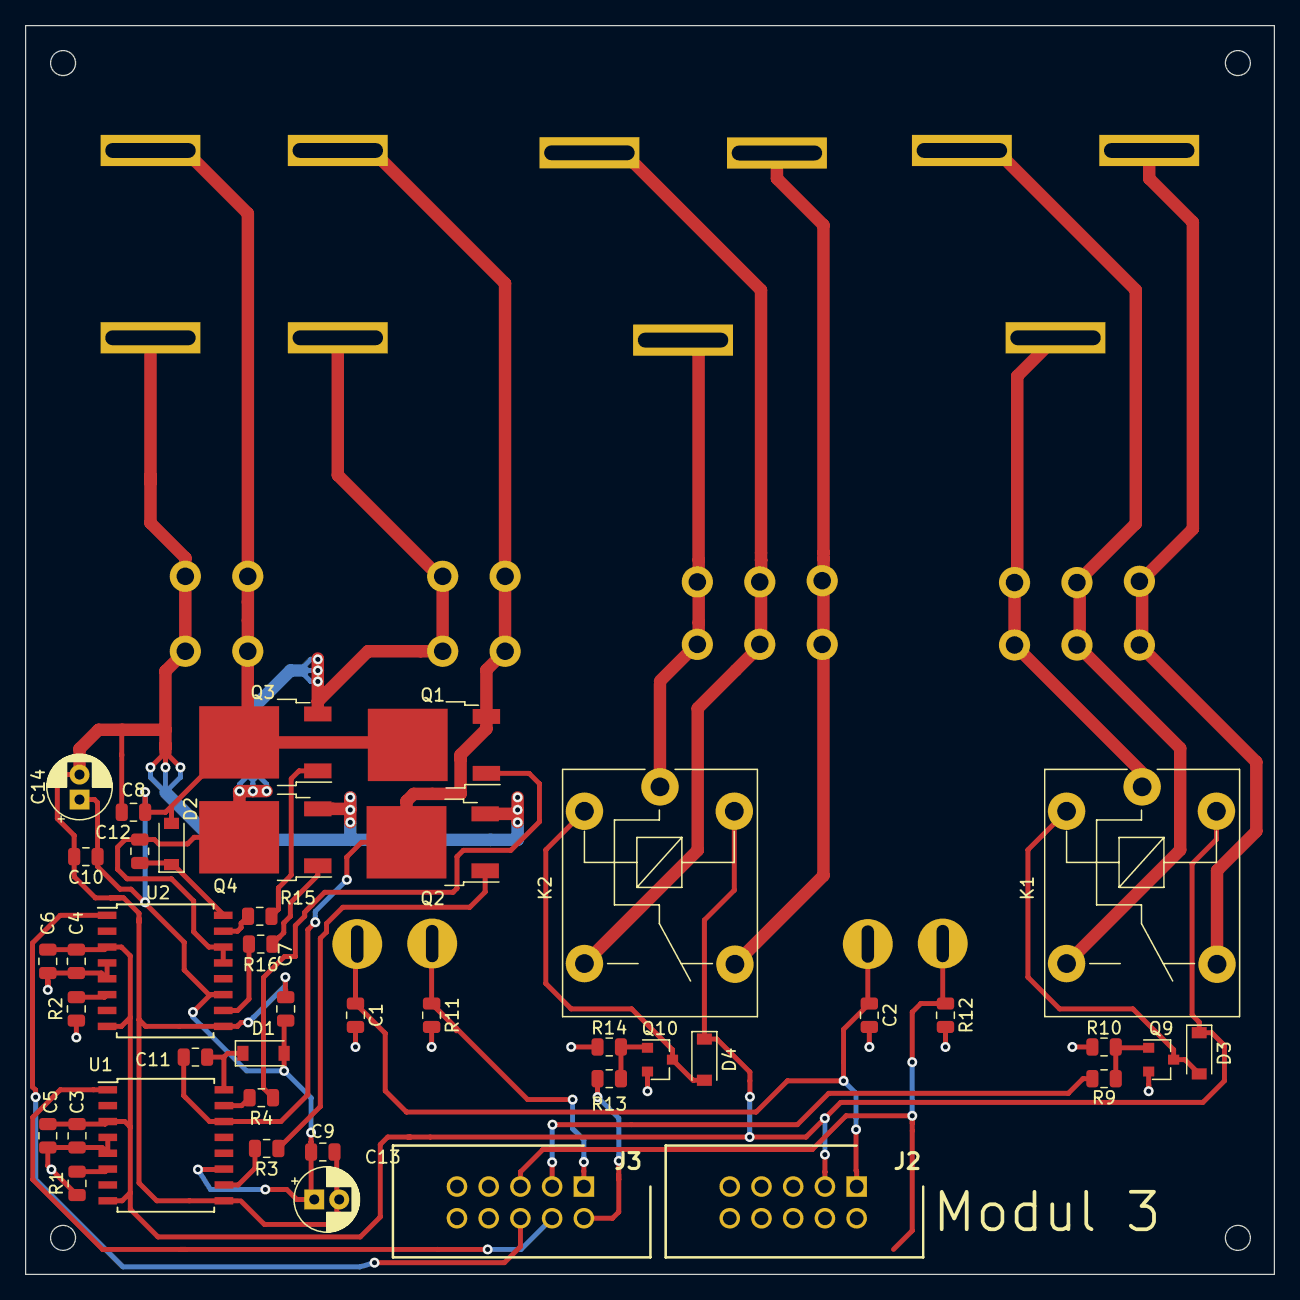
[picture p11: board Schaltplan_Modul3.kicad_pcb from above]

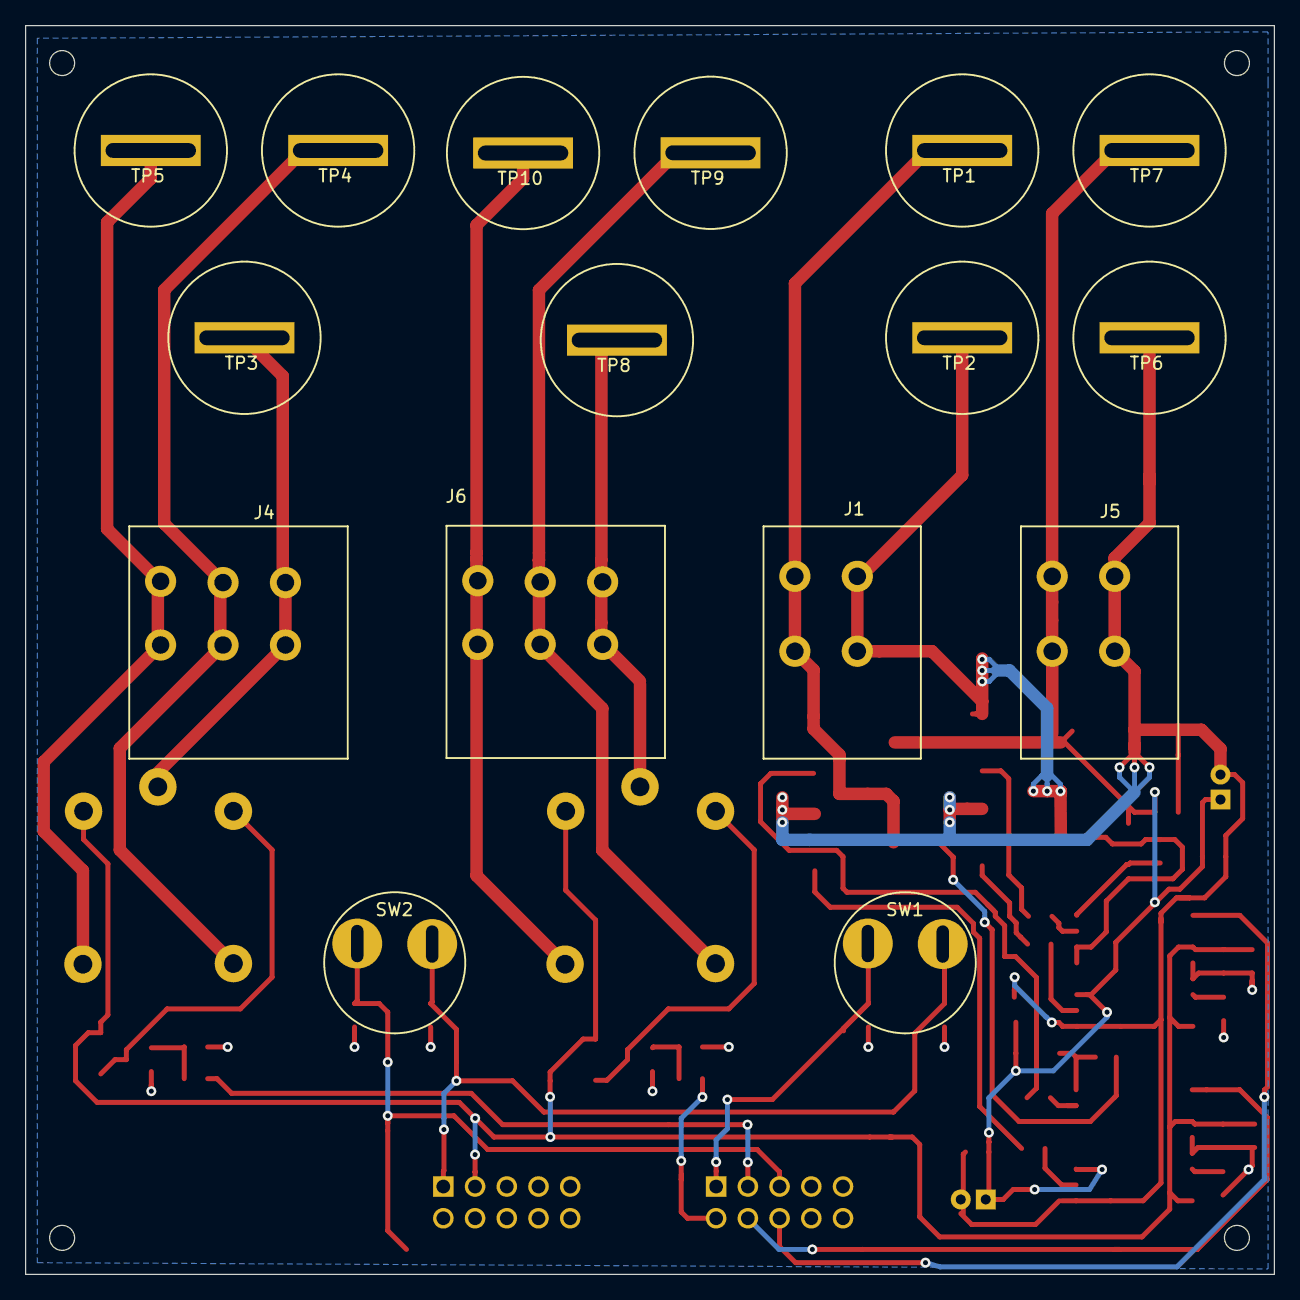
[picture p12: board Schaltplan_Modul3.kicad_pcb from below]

Board: 2 copper layers, 100.0 x 100.0 mm, 58 parts (16 on the bottom side), 35 nets.

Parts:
C1, C2: 10nF; C_0805_2012Metric
C3, C4, C9, C10: 100nF; C_0805_2012Metric
C5, C6, C7, C8, C11, C12: 1uF; C_0805_2012Metric
C13, C14: 10uF; CP_Radial_D5.0mm_P2.00mm
D1, D2, D3, D4: 1N4148; D_SOD-123
J1: Mosfets; TBL_127B 2
J2: ConnectorBUS_Rechts; SHDR10W64P254X254_2X5_2032X880X915P
J3: Connector_Rechts; SHDR10W64P254X254_2X5_2032X880X915P
J4, J6: Relais; TBL_127B 3
J5: Versorgung; TBL_127B 2
K1, K2: SANYOU_SRD_Form_C; Relay_SPDT_SANYOU_SRD_Series_Form_C
Q1, Q2, Q3, Q4: NVD5C454NT4G; TO-252-2
Q9, Q10: BC817; SOT-23
R1, R2: 100K; R_0805_2012Metric
R3, R4, R15, R16: 100R; R_0805_2012Metric
R9, R13: 5K6; R_0805_2012Metric
R10, R11, R12, R14: 10K; R_0805_2012Metric
SW1, SW2: SW_DIP_x01; Druckschalter
TP1, TP2: Geschalteter; BannaJack
TP3, TP8: 11; BannaJack
TP4, TP9: 14; BannaJack
TP5, TP10: 13; BannaJack
TP6: GND_Bannannenstecker; BannaJack
TP7: 6V-24VBannannenstecker; BannaJack
U1, U2: si8234bb; SOIC-16W_7.5x10.3mm_P1.27mm

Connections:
+3V3: C1.1, C2.1, J2.1, SW1.1, SW2.1
+5V: C3.1, C4.1, C5.1, C6.1, D3.1, D4.1, J2.3, K1.5, K2.5, U1.3, U1.8, U2.3, U2.8
+12V: C7.1, C8.1, C9.1, C10.1, C13.1, C14.1, D1.2, D2.2, J5.1, Q1.2, Q3.2, TP7.1, U1.11, U2.11
/IO2: J3.1, R11.1, SW1.2
/IO4: J3.2, R13.1
/IO13: J3.3, R9.1
/IO16: J3.4, U1.1
/IO17: J3.6, U2.1
/IO32: J3.5, R12.1, SW2.2
GND: C1.2, C2.2, C3.2, C4.2, C5.2, C6.2, J2.2, Q9.2, Q10.2, R1.1, R2.1, R10.2, R11.2, R12.2, R14.2, U1.4, U1.5, U2.4, U2.5
GNDS: C7.2, C8.2, C9.2, C10.2, C13.2, C14.2, J5.2, Q2.3, Q4.3, TP6.1, U1.9, U2.9
unnamed: C11.1, D1.1, U1.16
unnamed: C11.2, J1.1, Q1.3, Q2.2, TP1.1, U1.14
unnamed: C12.1, D2.1, U2.16
unnamed: C12.2, J1.2, Q3.3, Q4.2, TP2.1, U2.13, U2.14
unnamed: D3.2, K1.2, Q9.3
unnamed: D4.2, K2.2, Q10.3
unnamed: J4.1, K1.4, TP5.1
unnamed: J4.2, K1.3, TP4.1
unnamed: J4.3, K1.1, TP3.1
unnamed: J6.1, K2.4, TP10.1
unnamed: J6.2, K2.3, TP9.1
unnamed: J6.3, K2.1, TP8.1
unnamed: Q1.1, R4.1
unnamed: Q2.1, R3.1
unnamed: Q3.1, R15.1
unnamed: Q4.1, R16.1
unnamed: Q9.1, R9.2, R10.1
unnamed: Q10.1, R13.2, R14.1
unnamed: R1.2, U1.6
unnamed: R2.2, U2.6
unnamed: R3.2, U1.10
unnamed: R4.2, U1.15
unnamed: R15.2, U2.15
unnamed: R16.2, U2.10

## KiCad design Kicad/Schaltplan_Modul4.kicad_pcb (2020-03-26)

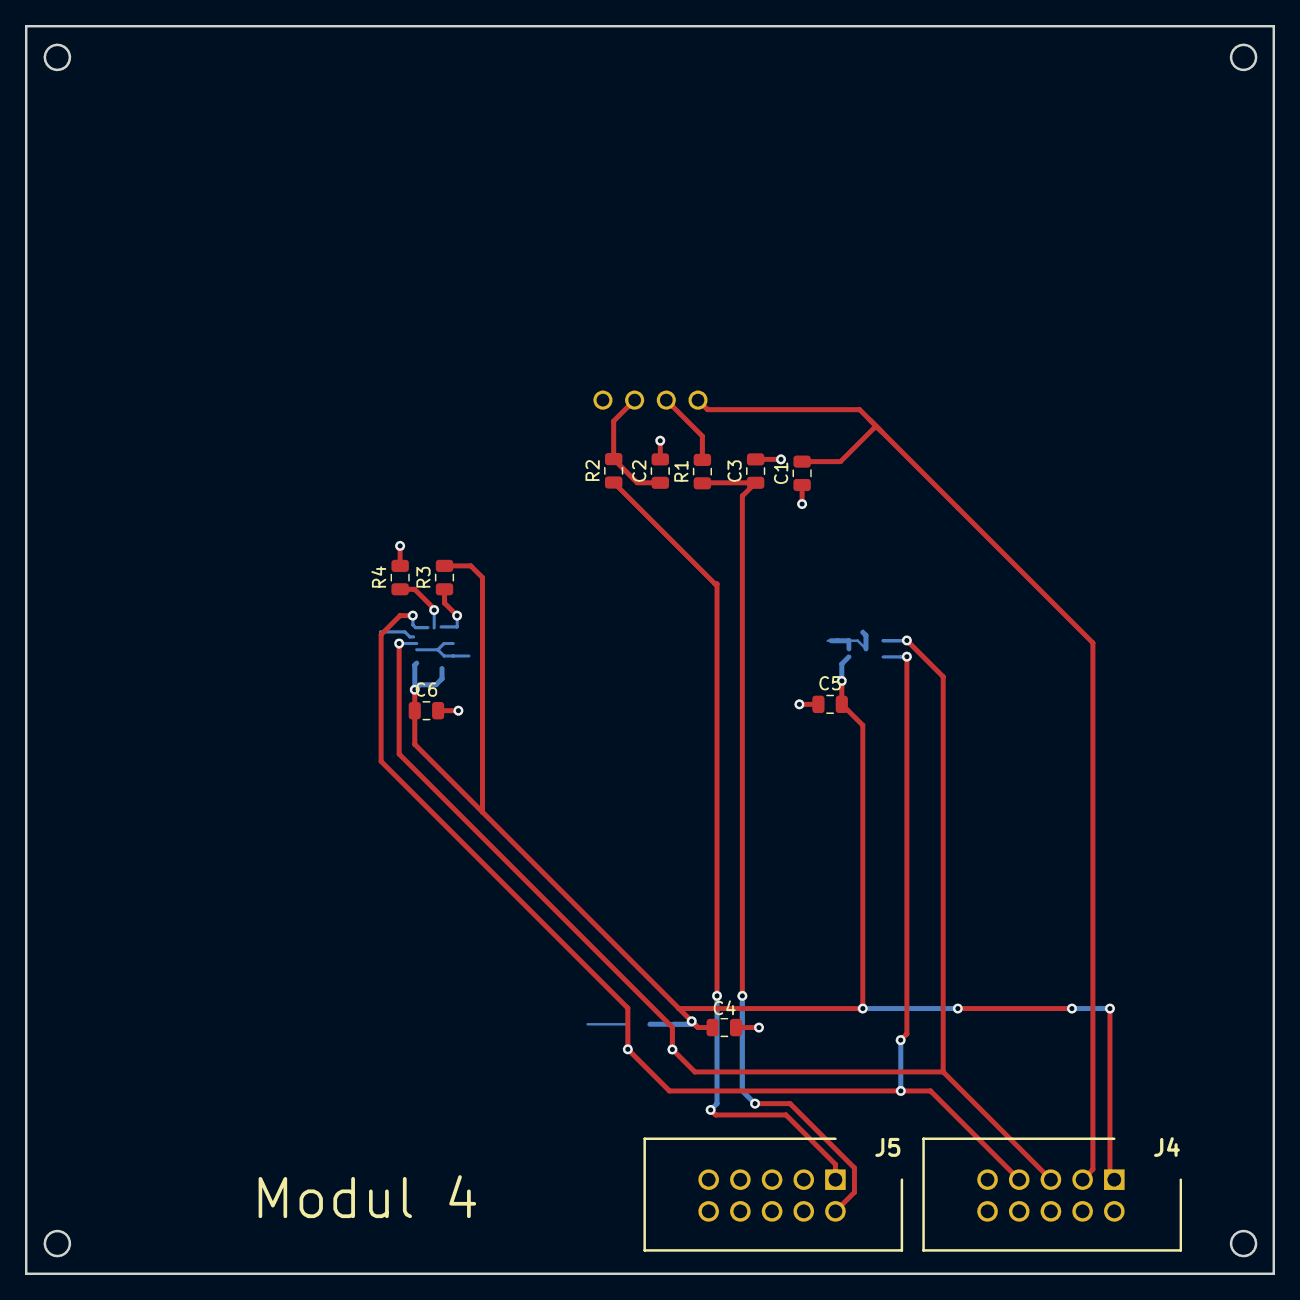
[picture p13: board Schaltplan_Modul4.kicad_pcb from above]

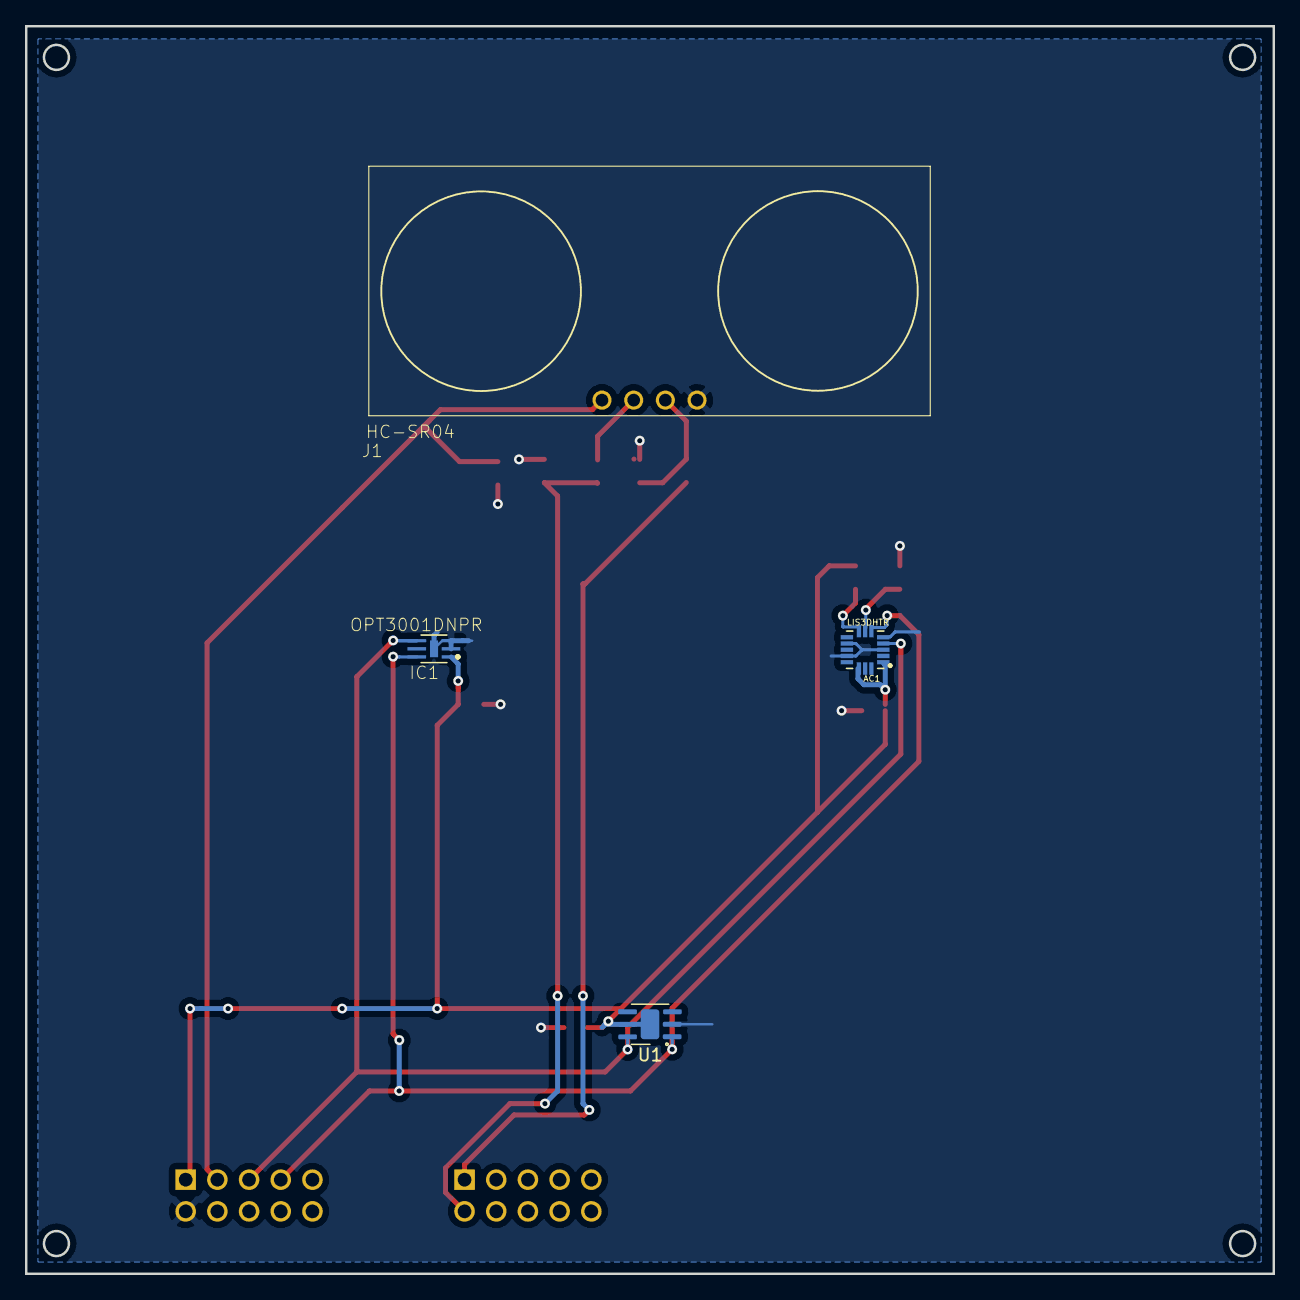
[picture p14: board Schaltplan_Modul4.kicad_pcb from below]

Board: 2 copper layers, 100.0 x 100.0 mm, 16 parts (4 on the bottom side), 11 nets.

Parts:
AC1: LIS3DHTR; XDCR_LIS3DHTR
C1, C4, C5, C6: 1pF; C_0805_2012Metric
C2, C3: 47pF; C_0805_2012Metric
IC1: OPT3001DNPR
J1: HC-SR04; XCVR_HC-SR04
J4: ConnectorBUS_Rechts; SHDR10W64P254X254_2X5_2032X880X915P
J5: Conn_02x01; SHDR10W64P254X254_2X5_2032X880X915P
R1, R2: 47R; R_0805_2012Metric
R3, R4: 10K; R_0805_2012Metric
U1: Si7020-A20; DFN-6-1EP_3x3mm_P1mm_EP1.5x2.4mm

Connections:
+3V3: AC1.1, AC1.14, C4.1, C5.2, C6.1, IC1.1, J4.1, R3.2, U1.5, U1.7
+5V: C1.2, J1.1, J4.3
/IO14: J5.1, R2.1
/IO27: C3.1, J5.2, R1.1
/SCL: AC1.4, IC1.4, J4.5, U1.6
/SDA: AC1.6, IC1.6, J4.7, U1.1
GND: AC1.3, AC1.5, AC1.10, AC1.12, C1.1, C2.2, C3.2, C4.2, C5.1, C6.2, IC1.2, IC1.3, IC1.7, J1.4, J4.2, R4.2, U1.2
unnamed: AC1.7, R4.1
unnamed: AC1.8, R3.1
unnamed: C2.1, J1.3, R2.2
unnamed: J1.2, R1.2

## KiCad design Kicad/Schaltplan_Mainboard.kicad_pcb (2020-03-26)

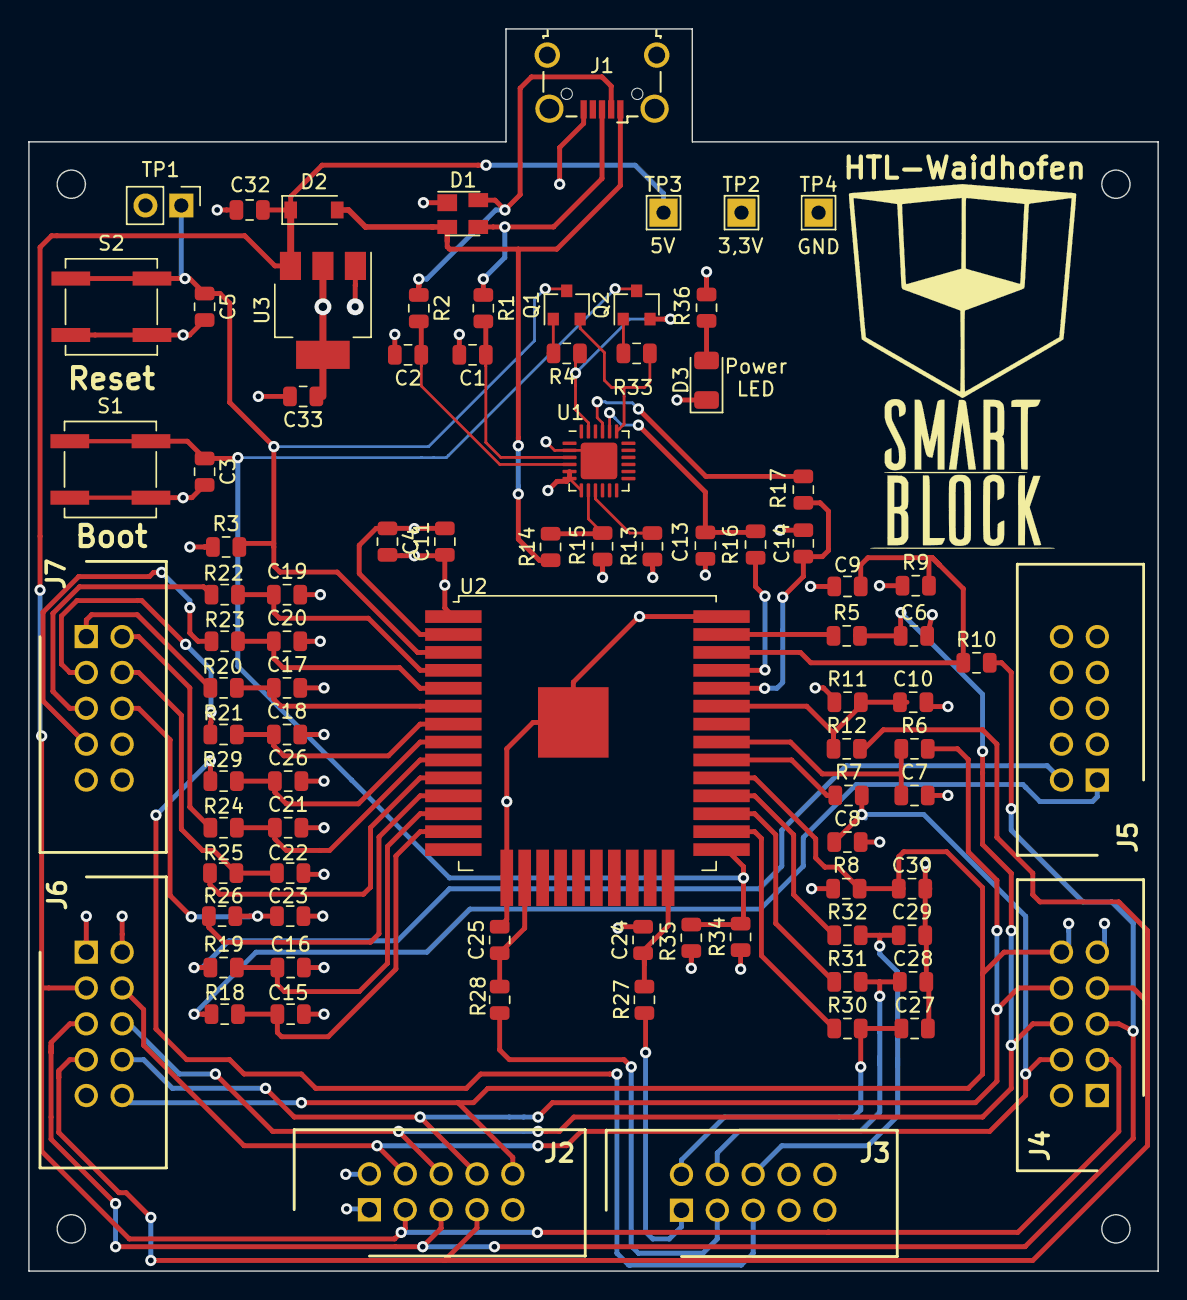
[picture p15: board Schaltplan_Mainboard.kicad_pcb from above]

Board: 4 copper layers, 80.0 x 88.0 mm, 88 parts (0 on the bottom side), 62 nets.

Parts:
C1, C2, C6, C7, C8, C9, C10, C13, C14, C15, C16, C17, C18, C19, C20, C21, C22, C23, C24, C25, C26, C27, C28, C29, C30: 47pF; C_0805_2012Metric
C3, C5: 0,1nF; C_0805_2012Metric
C4, C11, C32, C33: 1uF; C_0805_2012Metric
D1: SP0503BAHT; SOT-143
D2: 1N5819HW-7-F; D_SOD-123
D3: Led Spannung; LED_1206_3216Metric
J1: Micro-B_Wuerth_629105150521; USB_Micro-B_Wuerth_629105150521_CircularHoles
J2: ConnectorBUS_Front; SHDR10W64P254X254_2X5_2032X880X915P
J3: Connector_Front; SHDR10W64P254X254_2X5_2032X880X915P
J4: ConnectorBUS_Rechts; SHDR10W64P254X254_2X5_2032X880X915P
J5: Conn_Rechts; SHDR10W64P254X254_2X5_2032X880X915P
J6: ConnectorBUS_Links; SHDR10W64P254X254_2X5_2032X880X915P
J7: Connector_Links; SHDR10W64P254X254_2X5_2032X880X915P
Q1, Q2: BC817; SOT-23
R1, R2: 22R; R_0805_2012Metric
R3, R4, R8, R33, R34: 10K; R_0805_2012Metric
R5, R6, R7, R10, R12, R16, R17, R18, R19, R20, R21, R22, R23, R24, R25, R26, R27, R28, R29, R30, R31, R32: R47; R_0805_2012Metric
R9, R11: 4K7; R_0805_2012Metric
R13: 2K; R_0805_2012Metric
R14: 22,1K; R_0805_2012Metric
R15: 47,5k; R_0805_2012Metric
R35: 1M NC; R_0805_2012Metric
R36: 300R; R_0805_2012Metric
S1: BOOT Option; SW_SPST_B3SL-1002P
S2: Reset; SW_SPST_B3SL-1002P
TP1: Externer Reset; PinHeader_1x02_P2.54mm_Vertical
TP2: TestPoint 5V; TestPoint_THTPad_2.0x2.0mm_Drill1.0mm
TP3: TestPoint 3,3V; TestPoint_THTPad_2.0x2.0mm_Drill1.0mm
TP4: TestPoint GND; TestPoint_THTPad_2.0x2.0mm_Drill1.0mm
U1: CP2102N-A01-GQFN24; QFN-24-1EP_4x4mm_P0.5mm_EP2.6x2.6mm
U2: EP32-WROOM-32D; ESP32-WROOM-32U
U3: AMS1117-3.3; SOT-223-3_TabPin2

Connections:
+3V3: C4.1, C11.2, C33.1, J2.1, J4.1, J6.1, R3.1, R8.1, R9.1, R11.1, R13.1, R34.1, R36.1, TP2.1, U1.5, U1.6, U1.7, U2.2, U3.2
+5V: C32.1, D2.1, J2.3, J4.3, J6.3, TP3.1, U3.3
/DTR: Q2.2, R4.2, U1.23
/IO2: C24.1, R27.1, U2.24
/IO4: R30.1, U2.26
/IO13: C25.1, R28.1, U2.16
/IO14: C15.1, R18.1, U2.13
/IO16: R31.1, U2.27
/IO17: R32.1, U2.28
/IO25: R25.1, U2.10
/IO26: R26.1, U2.11
/IO27: C16.1, R19.2, U2.12
/IO32: C26.1, R29.1, U2.8
/IO33: C21.1, R24.1, U2.9
/IO34: C17.1, R20.1, U2.6
/IO35: C18.1, R21.1, U2.7
/IO36: C19.1, R22.1, U2.4
/IO39: C20.1, R23.1, U2.5
/RTS: Q1.2, R33.2, U1.19
/RXD: R16.2, U2.35
/SCL: J2.5, J4.5, J6.5, R10.2
/SCL_Raw: C9.1, R9.2, R10.1, U2.36
/SDA: J2.7, J4.7, J6.7, R12.2
/SDA_Raw: C10.1, R11.2, R12.1, U2.33
/TXD: C14.1, R17.2, U2.34
/USB1_DN: C2.1, R2.2, U1.4
/USB1_DP: C1.1, R1.2, U1.3
/VSPI_CLK: C8.1, J2.4, J4.4, J6.4, R7.2
/VSPI_CLK_Raw: R7.1, U2.30
/VSPI_CS: C30.1, J2.10, J4.10, J6.10, R8.2, U2.29
/VSPI_MISO: J2.8, J4.8, J6.8, R6.2
/VSPI_MISO_Raw: C7.1, R6.1, U2.31
/VSPI_MOSI: C6.1, J2.6, J4.6, J6.6, R5.2
/VSPI_MOSI_Raw: R5.1, U2.37
EN: C5.1, Q1.3, R3.2, S2.1, TP1.1, U2.3
GND: C1.2, C2.2, C3.2, C4.2, C5.2, C6.2, C7.2, C8.2, C9.2, C10.2, C11.1, C13.2, C14.2, C15.2, C16.2, C17.2, C18.2, C19.2, C20.2, C21.2, C22.2, C23.2, C24.2, C25.2, C26.2, C27.2, C28.2, C29.2, C30.2, C32.2, C33.2, D1.1, D3.1, J1.5, J2.2, J4.2, J6.2, R15.2, R35.2, S1.2, S2.2, TP1.2, TP4.1, U1.2, U1.25, U2.1, U2.15, U2.38, U2.39, U3.1
IO0: C3.1, Q2.3, R34.2, R35.1, S1.1, U2.25
unnamed: C13.1, R16.1, U1.20
unnamed: C22.1, J7.4, R25.2
unnamed: C23.1, J7.6, R26.2
unnamed: C27.1, J3.2, R30.2
unnamed: C28.1, J3.4, R31.2
unnamed: C29.1, J3.6, R32.2
unnamed: D1.3, J1.3, R1.1
unnamed: D1.4, J1.2, R2.1
unnamed: D3.2, R36.2
unnamed: J3.1, R27.2
unnamed: J3.3, R28.2
unnamed: J3.5, R29.2
unnamed: J5.1, R18.2
unnamed: J5.2, R19.1
unnamed: J7.1, R20.2
unnamed: J7.2, R24.2
unnamed: J7.3, R21.2
unnamed: J7.5, R22.2
unnamed: J7.7, R23.2
unnamed: Q1.1, R4.1
unnamed: Q2.1, R33.1
unnamed: R13.2, U1.9
unnamed: R14.2, R15.1, U1.8
unnamed: R17.1, U1.21
VBUS: D1.2, D2.2, J1.1, R14.1

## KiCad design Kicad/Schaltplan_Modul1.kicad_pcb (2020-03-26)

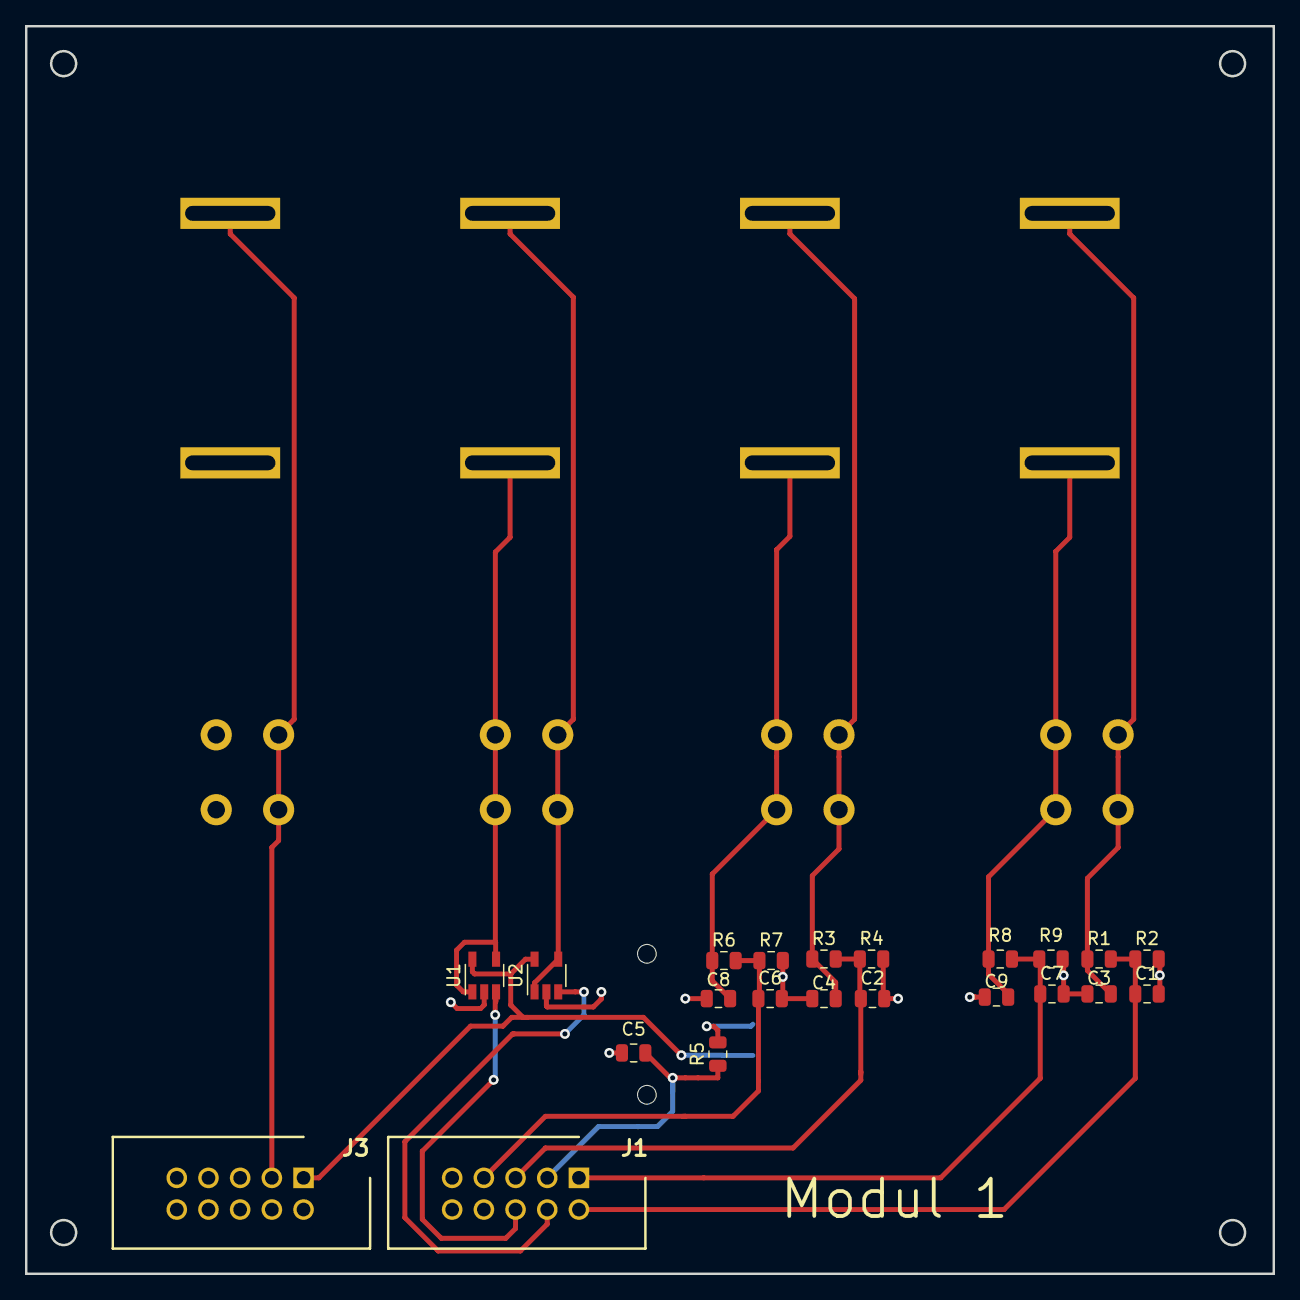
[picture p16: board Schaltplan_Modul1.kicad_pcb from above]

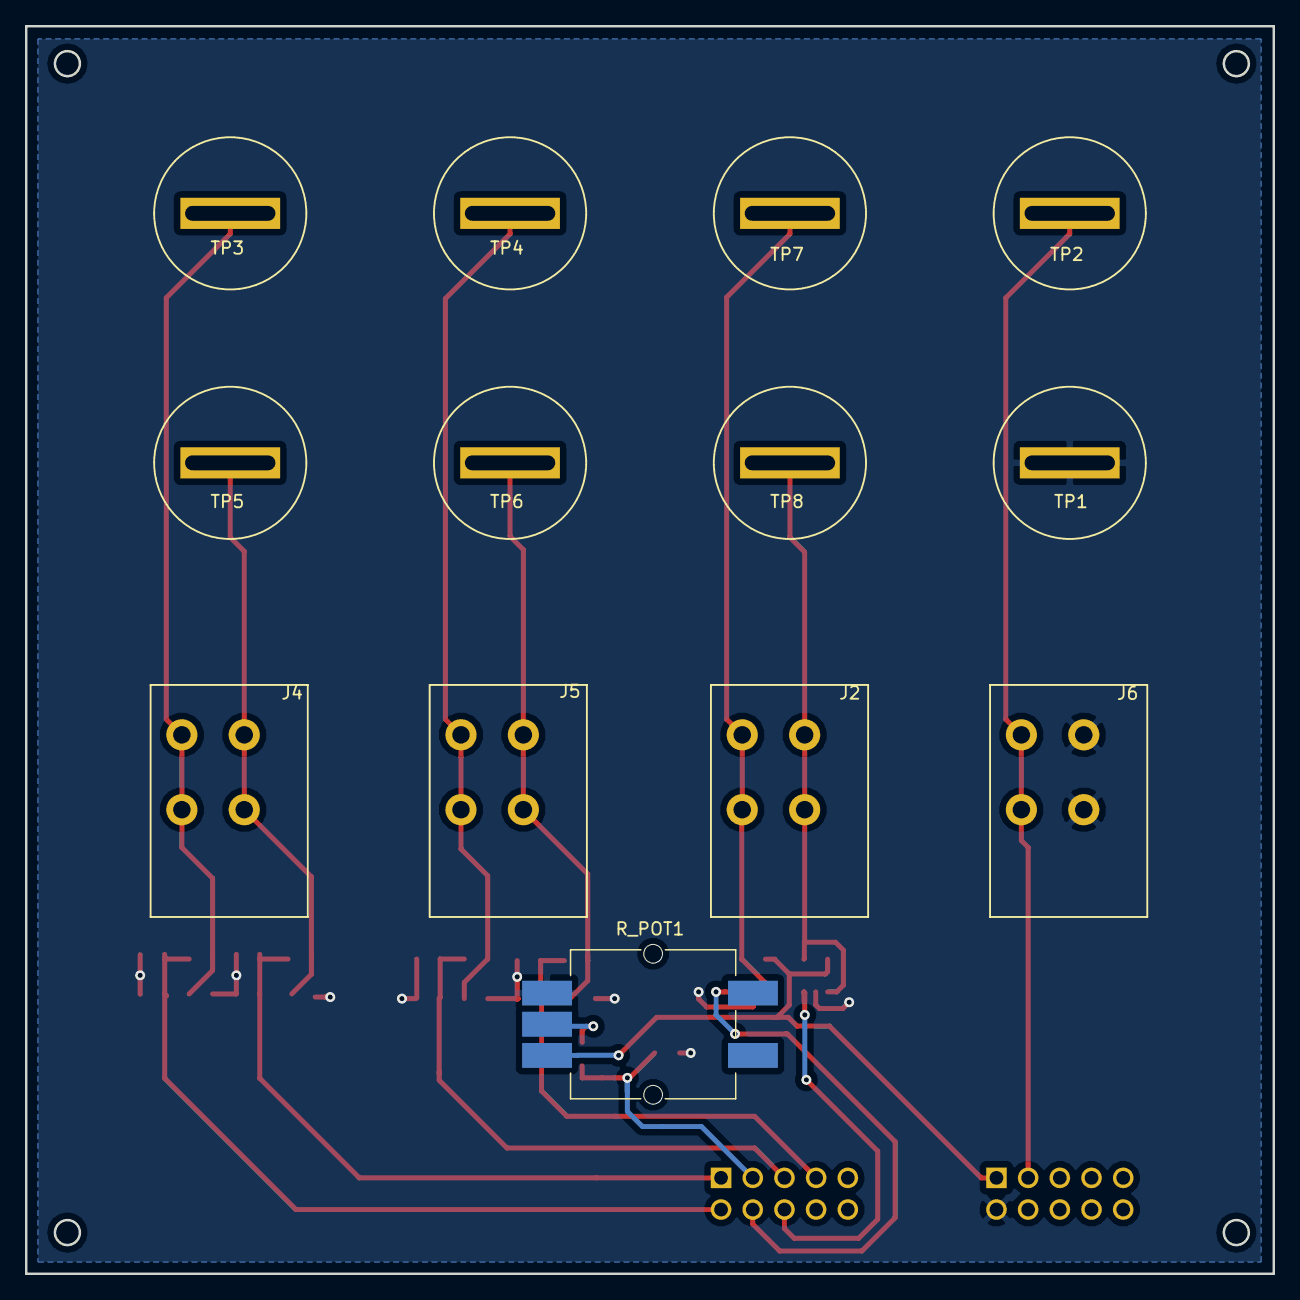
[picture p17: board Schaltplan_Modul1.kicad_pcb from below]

Board: 2 copper layers, 100.0 x 100.0 mm, 35 parts (13 on the bottom side), 17 nets.

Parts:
C1, C2, C3, C4, C5, C6, C7, C8, C9: 10nF; C_0805_2012Metric
J1: Connector_Links; SHDR10W64P254X254_2X5_2032X880X915P
J2: X_DAC; TBL_127B 2
J3: ConnectorBUS_Links; SHDR10W64P254X254_2X5_2032X880X915P
J4: X_AI_24V; TBL_127B 2
J5: X_AI_10V; TBL_127B 2
J6: X_AI_Versorgung; TBL_127B 2
R1, R3, R6, R8: 10K; R_0805_2012Metric
R2, R9: 1K6; R_0805_2012Metric
R4, R7: 4K7; R_0805_2012Metric
R5: 100R; R_0805_2012Metric
R_POT1: 10K_Pot; Potentiometer_Bourns_PRS11S_Vertical
TP1: GND Bananenbuchse; BannaJack
TP2: 5V Bannanenbuchse; BannaJack
TP3, TP5: Ai 24V Bananenbuchse; BannaJack
TP4, TP6: Ai 10V Bananenbuchse; BannaJack
TP7, TP8: DAC; BannaJack
U1, U2: AD8603; TSOT-23-5

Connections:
+3V3: J3.1, R_POT1.3, U1.5, U2.5
+5V: J3.3, J6.1, TP2.1
/IO25: J1.4, U2.3
/IO26: J1.6, U1.3
/IO33: C1.1, J1.2, R1.2, R2.1
/IO34: C7.1, J1.1, R8.2, R9.1
/IO35: C5.1, J1.3, R5.1
/IO36: C2.1, J1.5, R3.2, R4.1
/IO39: C6.1, J1.7, R6.2, R7.1
GND: C1.2, C2.2, C3.2, C4.2, C5.2, C6.2, C7.2, C8.2, C9.2, J3.2, J6.2, R2.2, R4.2, R7.2, R9.2, R_POT1.1, TP1.1, U1.2, U2.2
unnamed: C3.1, J4.1, R1.1, TP3.1
unnamed: C4.1, J5.1, R3.1, TP4.1
unnamed: C8.1, J5.2, R6.1, TP6.1
unnamed: C9.1, J4.2, R8.1, TP5.1
unnamed: J2.1, TP7.1, U2.1, U2.4
unnamed: J2.2, TP8.1, U1.1, U1.4
unnamed: R5.2, R_POT1.2

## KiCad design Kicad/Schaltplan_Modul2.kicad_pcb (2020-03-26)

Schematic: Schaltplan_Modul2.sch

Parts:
C1, C2, C3, C4, C5: 10nF; C_0805_2012Metric
D1, D2, D3: Led THT; D_DO-15_P5.08mm_Vertical_KathodeUp
J1: ConnectorBUS_Front; SHDR10W64P254X254_2X5_2032X880X915P
J2: Connector_Front; SHDR10W64P254X254_2X5_2032X880X915P
J3: LCD Dobrovitz; LCD_dobro
Q1: BC817; SOT-23
R1, R2, R6, R8: 10k; R_0805_2012Metric
R3, R5, R7: 220R; R_0805_2012Metric
RV1: R_POT 10k; Potentiometer_Bourns_3314G_Vertical
SW1, SW3, SW4: SW_DIP_x01; Druckschalter
U1: PCF8574; SOIC-16W_7.5x10.3mm_P1.27mm

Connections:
+3V3: C2.1, C4.1, C5.1, J1.1, SW1.1, SW3.1, SW4.1
+5V: C1.2, J1.3, J3.2, J3.16, RV1.1, U1.16 (VDD)
/IO2: J2.1, R1.1, SW1.2
/IO4: J2.2, R3.1
/IO13: J2.3, R6.1, SW3.2
/IO16: J2.4, R5.1
/IO17: J2.6, R7.1
/IO32: J2.5, R8.1, SW4.2
/SCL: J1.5, U1.14 (SCL)
/SDA: J1.7, U1.15 (SDA)
/VSPI_CLK: J1.4
/VSPI_CS: J1.10
/VSPI_MISO: J1.8
/VSPI_MOSI: J1.6
GND: C1.1, C2.2, C3.1, C4.2, C5.2, D1.1, D2.1, D3.1, J1.2, J3.1, Q1.2, R1.2, R6.2, R8.2, RV1.3, U1.1 (A0), U1.2 (A1), U1.3 (A2), U1.8 (VSS)
unnamed: C3.2, R2.1, U1.7 (P3)
unnamed: D1.2, R3.2
unnamed: D2.2, R5.2
unnamed: D3.2, R7.2
unnamed: J3.3, RV1.2
unnamed: J3.4, U1.4 (P0)
unnamed: J3.5, U1.5 (P1)
unnamed: J3.6, U1.6 (P2)
unnamed: J3.11, U1.9 (P4)
unnamed: J3.12, U1.10 (P5)
unnamed: J3.13, U1.11 (P6)
unnamed: J3.14, U1.12 (P7)
unnamed: J3.15, Q1.3
unnamed: Q1.1, R2.2

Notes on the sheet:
Modul 2
LCD i2C
Stecker
LEDs
Taster

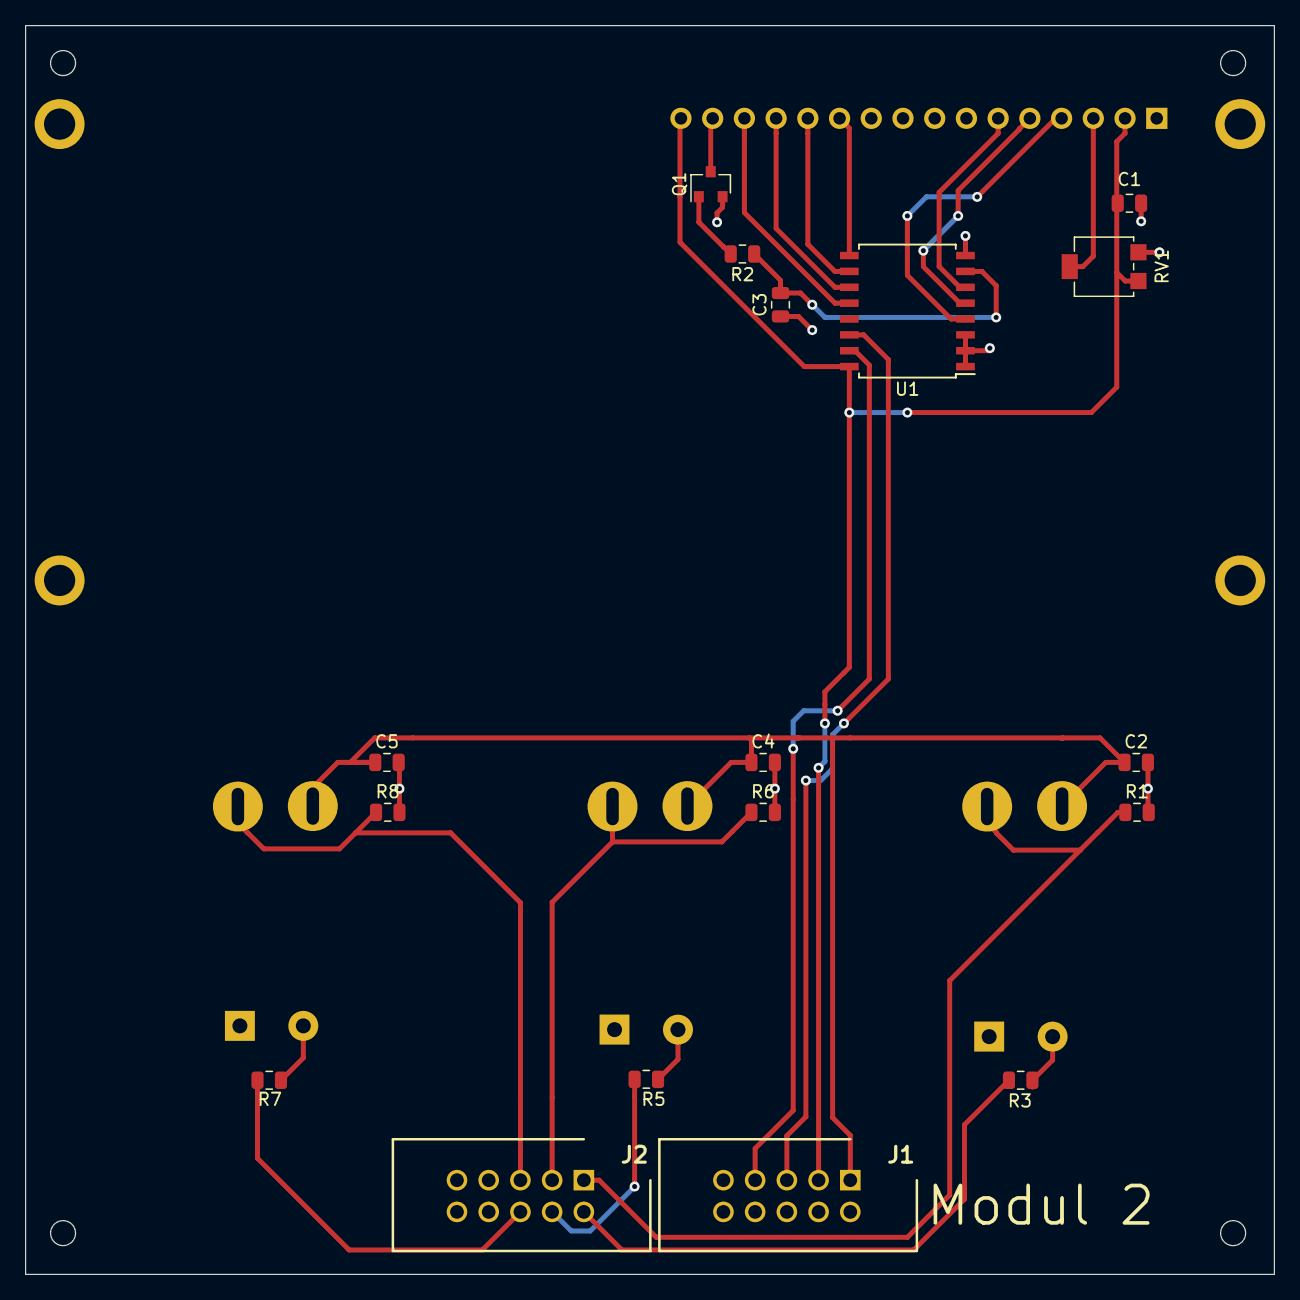
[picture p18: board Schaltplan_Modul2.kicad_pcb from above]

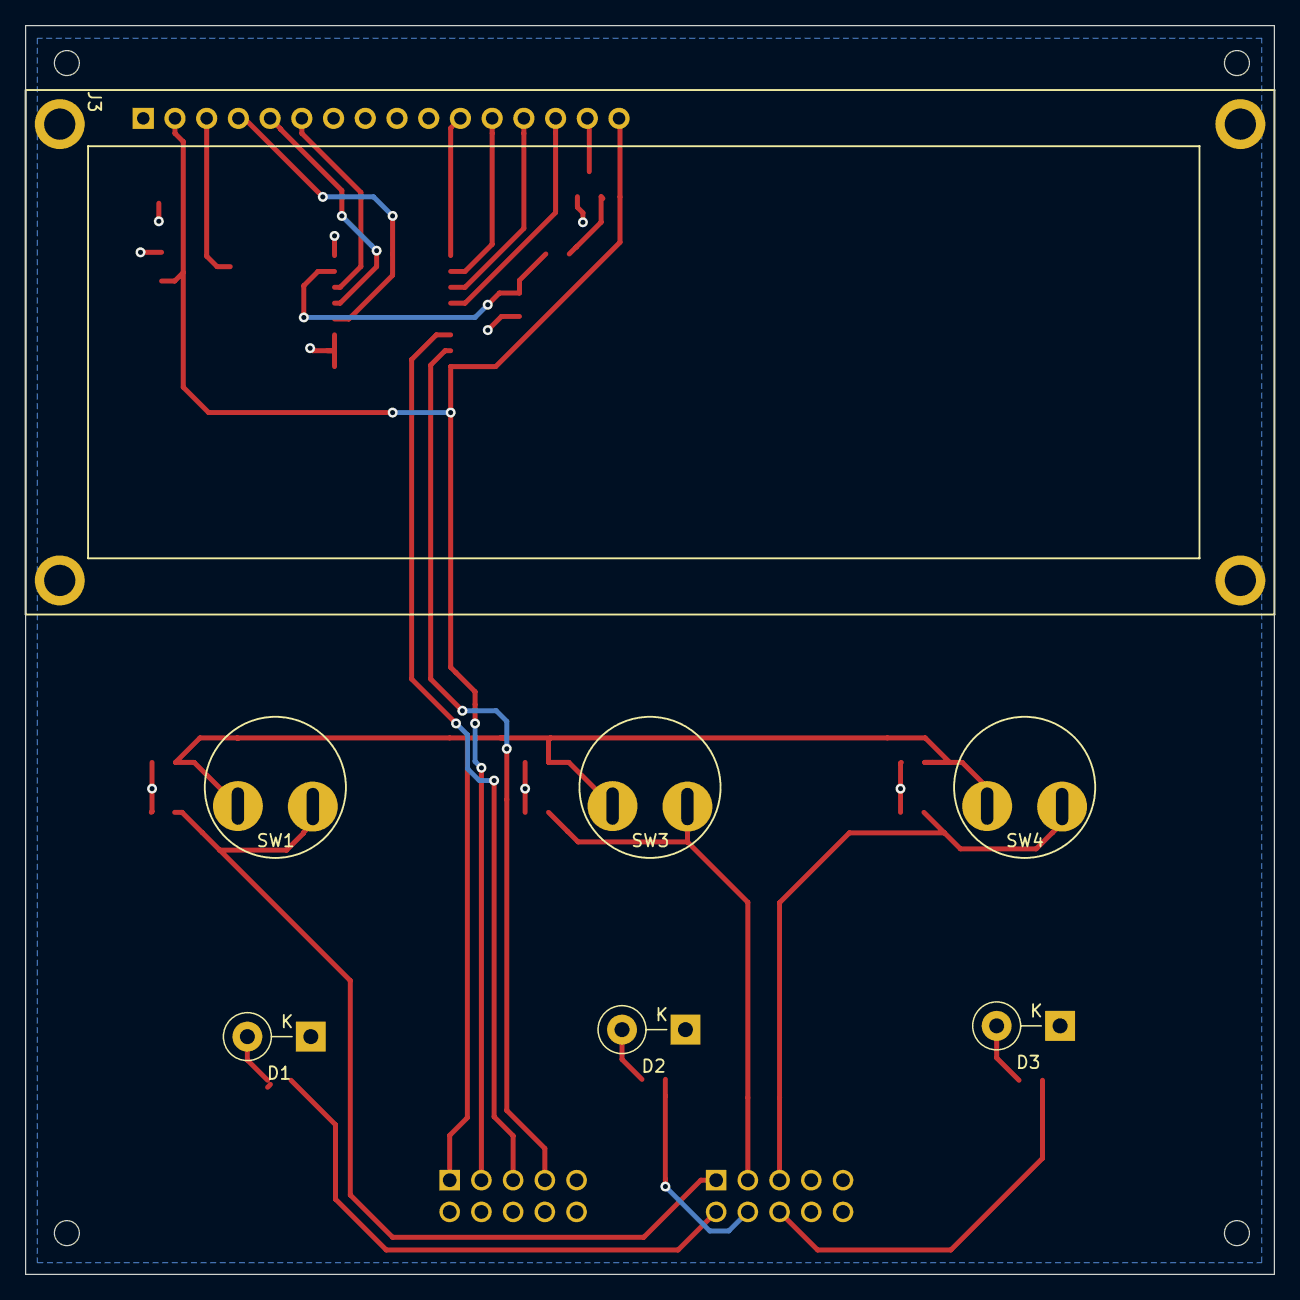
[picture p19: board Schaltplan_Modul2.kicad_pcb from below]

Board: 2 copper layers, 100.0 x 100.0 mm, 24 parts (7 on the bottom side), 25 nets.

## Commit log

2020-03-26 Erster commit. Es wurden die benötigten KiCAD Dateien hinzugefügt.
    [Bestückliste.xlsx, ESP32-WROOM-32U .stp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]
2020-03-26 Delete Bestückliste.xlsx
    Deleted due to internal changes.
    [Bestückliste.xlsx]
2020-03-30 Smartbocks.pdf and Stückliste.xlsx were outdated.
    [Stückliste.xlsx]
